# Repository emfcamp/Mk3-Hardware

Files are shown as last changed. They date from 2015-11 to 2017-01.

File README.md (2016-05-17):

Hardware
========

Hardware for the TiLDA MKπ Badge for [Electromagnetic Field
2016](https://www.emfcamp.org).

Key Specs
---------
* [STM32L486VGT6](http://www.st.com/content/st_com/en/products/microcontrollers/stm32-32-bit-arm-cortex-mcus/stm32l4-series/stm32l4x6/stm32l486vg.html):
  80MHz ultra-low-power ARM Cortex M4 microcontroller. 1MB Flash, 128KB
  SRAM, USB2. Micropython compatible.
* [CC3100MOD](http://www.ti.com/product/CC3100MOD) SimpleLink WiFi
  Network Processor.
* [LSM6DS3](http://www.st.com/content/st_com/en/products/mems-and-sensors/inemo-inertial-modules/lsm6ds3.html)
  3D accelerometer/gyro.
* [LIS3MDL](http://www.st.com/content/st_com/en/products/mems-and-sensors/e-compasses/lis3mdl.html)
  3D magnetometer.

License
-------
Copyright Electromagnetic Field Ltd. 2016

This documentation describes Open Hardware and is licensed under the
CERN OHL v. 1.2.  You may redistribute and modify this documentation
under the terms of the CERN OHL v.1.2. (http://ohwr.org/cernohl or the
LICENSE file in this repository). This documentation is distributed
WITHOUT ANY EXPRESS OR IMPLIED WARRANTY, INCLUDING OF MERCHANTABILITY,
SATISFACTORY QUALITY AND FITNESS FOR A PARTICULAR PURPOSE. Please see
the CERN OHL v.1.2 for applicable conditions.

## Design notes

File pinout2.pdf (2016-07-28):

PA0 | PA1 | PA2 | PB11
X1 | X2 | X3 | X4

WS2812

X1 | X2 | X3 | X4

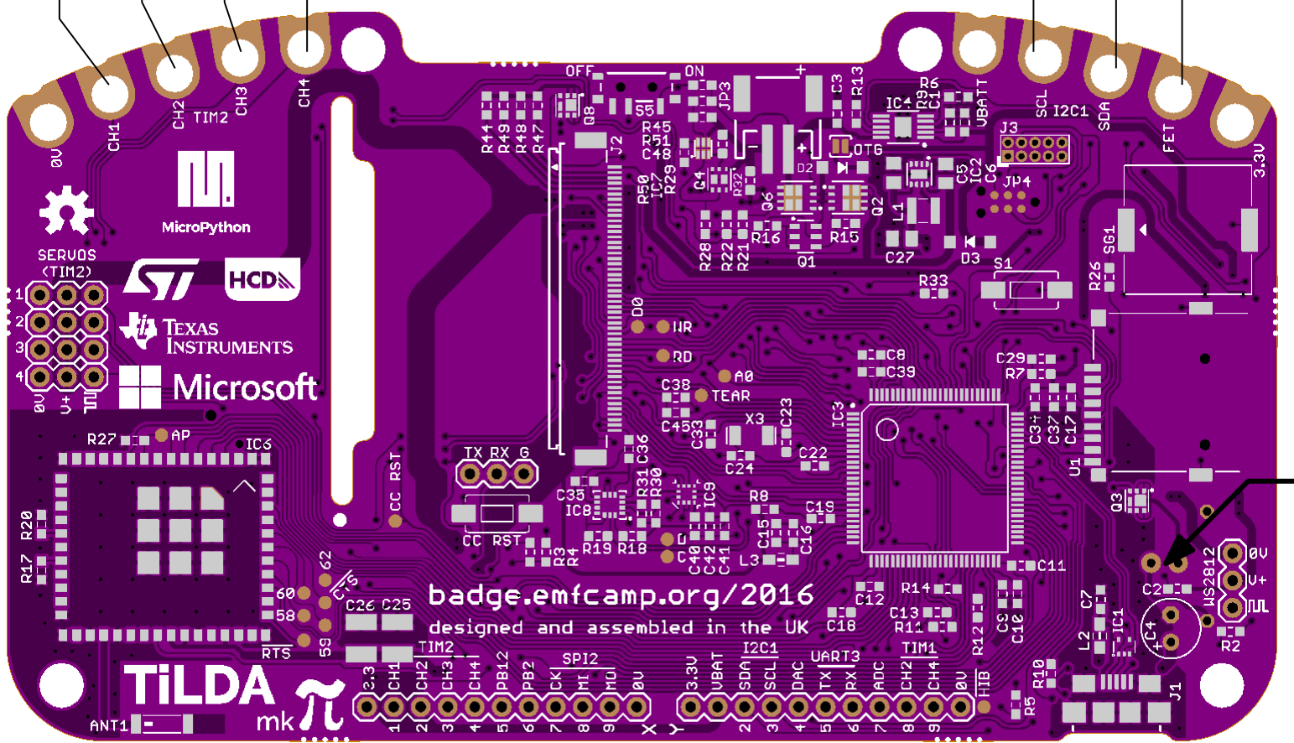
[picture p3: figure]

X1
X2
X3
X4

UART4
TX | RX
| TIM5
CH1 | CH2 | CH3

TIM2
CH1 | CH2 | CH3 | CH4
| ADC

## name

## Pin name

## Key peripherals

## Micropython

Y3 | Y2
PB9 | PB8
Y2 | Y3
PC7

## LED TORCH

I2C1
SDA | SCL

TIM4
CH4 | CH3

TIM4
CH2

## LED TORCH

This pin is open
drain | through | a
N-channel | FET.
Can | be | used
to | drive | higher
current loads

WS2812

## LED TORCH

PB13

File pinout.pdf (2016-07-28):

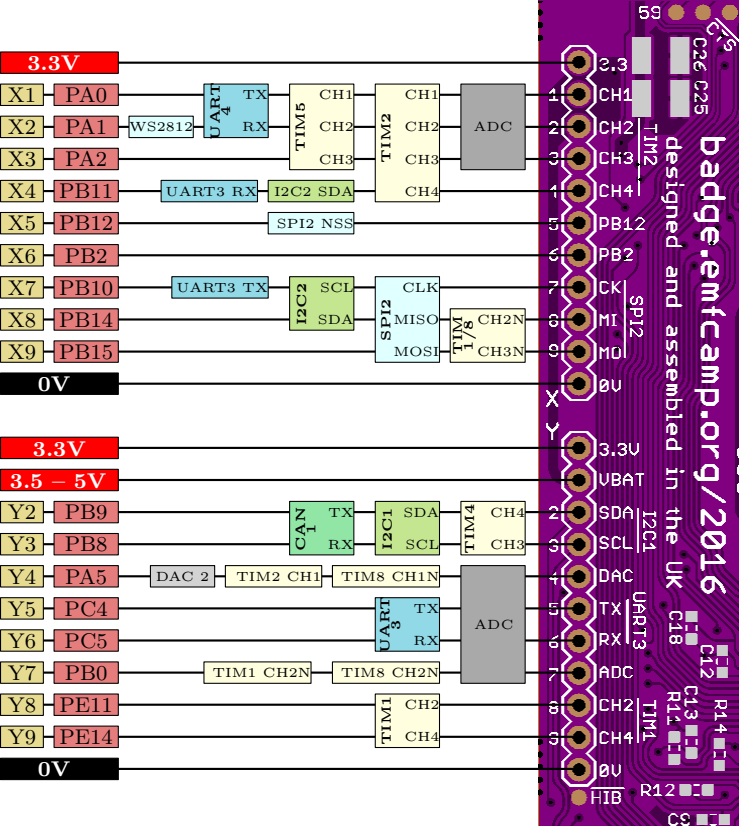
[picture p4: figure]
TIM2; CLK; MISO; MOSI; SPI2; SPI2 NSS; SDA; SCL; UART; TIM5; I2C2 SDA; UART3 TX; CAN; DAC 2; TIM2 CH1; TIM8 CH1N; TIM1 CH2N; TIM8 CH2N; TIM4; TIM1; TIM 1/8; UART3 RX; ADC

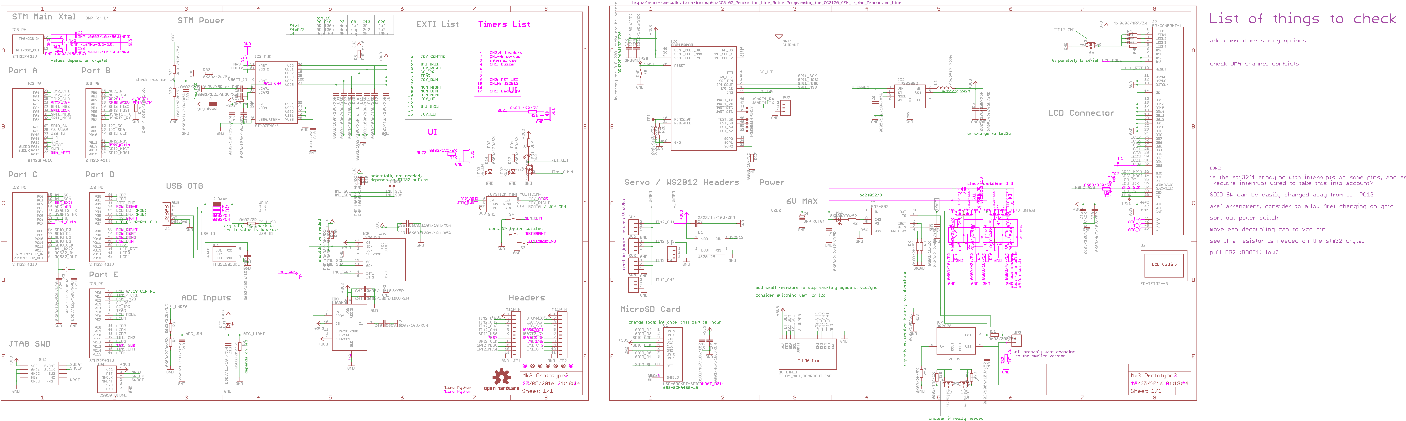
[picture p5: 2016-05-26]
diff v2_3.png

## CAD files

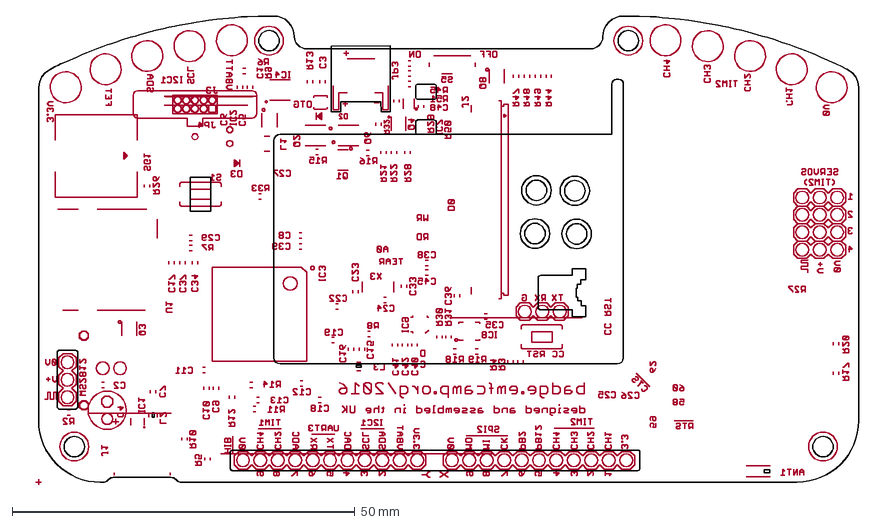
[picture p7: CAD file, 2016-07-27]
case-final.dxf
122.9 x 68.4 mm

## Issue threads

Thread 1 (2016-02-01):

Board Prototype 1 Issues

mattbrejza, 2016-02-01:
Potential leakage through R45 if battery cutoff is active but power switch is on. Leakage of 220K us ~16uA, so either increase this resistor, or rework the power section a bit

dpslwk, 2016-08-15:
No longer an issue

Closed 2016-08-15.

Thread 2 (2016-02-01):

Prototype -> Production Changes

mattbrejza, 2016-02-01:
Consider replacing 0R with solder jumpers

dpslwk, 2016-08-15:
No longer an issue

Closed 2016-08-15.

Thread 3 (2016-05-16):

Prototype 2 Issues

mattbrejza, 2016-05-16:
Check if WS2812 is fine on 3.3V, otherwise move to Vbat

mattbrejza, 2016-05-18:
consider switching PA5 and PE11 for DAC on external headers

mattbrejza, 2016-05-18:
consider connecting WS2812 to a timer pin

dpslwk, 2016-05-19:
Missing drill hole for screen mounting/location peg

‘RepRap’ Matt

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

dpslwk, 2016-05-19:
Move the CC serial header so its not under the screen

‘RepRap’ Matt

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

dpslwk, 2016-05-19:
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

Cutout example for screen ribbon

mattbrejza, 2016-05-19:
round corners near 3.3V/0V holes more

mattbrejza, 2016-05-19:
remove HSE and wire touchscreen

mattbrejza, 2016-05-19:
switch A/B and joystick

Jonty, 2016-05-19:
find wurth electronik passives we can swap in

mattbrejza, 2016-05-19:
move 5mm LED more inwards

mattbrejza, 2016-05-19:
look at buzzer options

dpslwk, 2016-05-19:
thinking we should move the LED to the bottom of the board/below the SD socket, so its not in you hand when you hold the badge

mattbrejza, 2016-05-19:
fiducials in opposite corners

dpslwk, 2016-05-19:
do something with the 11 way connectors so they are in something we can buy and does not need modifying
pin header socket size are normally  2,3,4,5,6,8,10.15,16,20,25

mattbrejza, 2016-05-20:
change footprints of microusb, switches to final ones

mattbrejza, 2016-05-20:
consider only having tagconnect

dpslwk, 2016-05-20:
Keep the SWD JTAG, not everyone can afford a Tag connect as well as a debugger
We are not populating it but might buy ~100 headers and sell them

'RepRap' Matt

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

dpslwk, 2016-05-20:
6x6 Tac switch foot print could have smaller pads and a little closer together
also add fancy alps pads just in case

‘RepRap’ Matt

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

dpslwk, 2016-05-20:
See if we can get a Plastic lanyard clip sample asap and then check the  clip size and what hole it will need.

'RepRap' Matt

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

mattbrejza, 2016-05-21:
if connecting touchscreen, make sure goes to ADC2, leaving ADC1 for user

mattbrejza, 2016-05-22:
add testpoints to parallel control sigs + one data

mattbrejza, 2016-05-22:
increase resistor for charge LED

mattbrejza, 2016-05-22:
mark on the silk where to place the velcro for the battery

mattbrejza, 2016-05-23:
Comments moved to other issues

Closed 2016-05-23.

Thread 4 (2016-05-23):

Board 2 Issues - Outline, stop, footprints,  misc

mattbrejza, 2016-05-23:
|  Item | Notes  | Progress |
|---|---|---|
| Teardrops on final board, do some test runs on copy of brd file | | |
| Ant pad, less exposed copper and cream | | ✔|
| Round corners on lcd ribbon slot, use 2mm wire as template in milling layer | | ✔|
| Don't like combined SD footprint, needs work | Will fix once decided on final part |✔|
| round corners near 3.3V/0V holes more | MB - I think they're fine| ✔|
| round corners near USB/wifi more | |✔|
| Missing drill hole for screen mounting/location peg | what size drill? (see comment)|✔ |
| fiducials in opposite corners | | LWK check please ✔|
| Larger stop around mcu and fpc connector pads, or make sure board house removes fingers | | |
| change footprints of microusb, switches to final ones | | ✔ |
| Remove cream from tag connector |I think just a dpcbs stencil 'artifact' |✔ Confirmed, no action needed |
| find wurth electronik passives we can swap in | |✔ |
| 6x6 Tac switch foot print could have smaller pads and a little closer together also add fancy alps pads just in case | |✔ |
| See if we can get a Plastic lanyard clip sample asap and then check the  clip size and what hole it will need. | | |
| LWK to review LGA footprint pad/cream sizes |Make sure there not too small | |
| Finalize battery connector selection. Suggest looking at JST PA (locking pin, less wire stress | | PH fine ✔|
| rename net TIM1_CH1N to TIM8_CH2 (for LED FET) | | ✔|

mattbrejza, 2016-05-23:
Example image of screen peg: https://www.dropbox.com/s/eqn3t87pvbxqiao/IMG_4801.jpg?dl=0

dpslwk, 2016-08-15:
No longer an issue

Closed 2016-08-15.

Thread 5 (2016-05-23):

Board 2 Issues - Values

mattbrejza, 2016-05-23:
|  Item | Notes  | Progress |
|---|---|---|
| D2 and D3 need values in schematic |rate D3 to 2A | ✔|
| increase resistor for charge LED | | |
| look at brightness of all LEDs | | |
| decide on buzzer resistor | | |

dpslwk, 2016-08-15:
No longer an issue

Closed 2016-08-15.

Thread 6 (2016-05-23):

Board 2 Issues - Silk

mattbrejza, 2016-05-23:
|  Item | Notes  | Progress |
|---|---|---|
| Ic7 name and thicker silk | | ✔|
| Rotate c42-40 labels | |✔|
| R9 label rotate; R31 label rotate | |✔ |
| Ic7 label | | ✔|
| Increase screen slik outline line thickness to 0.15mm | | ✔|
| Remove place silk from 0603s | MB disagrees |✔ |
| Test pad names on silk | | ✔|
| Servo squiggle too small, 0.15-0.3 min thickness and clearance | | ✔|
| S5 J3 move names outside parts | |✔ |
| Duplicate conductive pad labels to both sides | |✔ |
| Q1 pin one mark bigger | |✔ |
| Make sure no silk labels are under screen ribbon (CC serial header is right now) | |✔ |
| Header pin function labels need moving away from numbers | |✔ |
| Remove silk on jtag header, add pin 1 mark | | ✔|
| mark on the silk where to place the velcro for the battery | | |
| Add XYZ indicator for IMU | | |
| Add label to stm32 rst |||

dpslwk, 2016-08-15:
No longer an issue

Closed 2016-08-15.

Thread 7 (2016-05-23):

Board 2 Issues - Placement and Routing

mattbrejza, 2016-05-23:
|  Item | Notes  | Progress |
|---|---|---|
| LGA12/LGA14 footprints mirrored  | Re-routing also needed  | ✔  |
| switch A/B and joystick | |✔ |
| Add option to bypass battery protection if not fitted | | ✔|
| remove HSE and wire touchscreen | touchscreen not yet confirmed. if connecting touchscreen, make sure goes to ADC2, leaving ADC1 for user | ✔|
| thinking we should move the LED to the bottom of the board/below the SD socket, so its not in you hand when you hold the badge; move 5mm LED more inwards | |✔|
| Move A, B LEDs away from screen | | ✔ |
| Add reset button for STM?| same switch as MENU? |✔ |
| X3 is long way from mcu, check ok| |✔ - its only 32kHz, and not that far |
| Can we get ic4 in something other than msop-10? |  | ✔ nope |
| Test pad  add more | add testpoints to parallel control sigs + one data ✔ | |
| Speaker too close to the edge | | ✔|
| Move the CC serial header so its not under the screen | | |
| consider switching PA5 and PE11 for DAC on external headers | |✔ |
| consider connecting WS2812 to a timer pin | |✔ |
| do something with the 11 way connectors so they are in something we can buy and does not need modifying pin header socket size are normally 2,3,4,5,6,8,10.15,16,20,25 | | |
| Check if WS2812 is fine on 3.3V, otherwise move to Vbat | | ✔|
| Check meander on usb trace | | ✔ close enough |
| Battery option 3 | |✔ |
| R23 sort out | |✔|
| Test point on CC_HIB | | ✔|

dpslwk, 2016-08-15:
No longer an issue

Closed 2016-08-15.

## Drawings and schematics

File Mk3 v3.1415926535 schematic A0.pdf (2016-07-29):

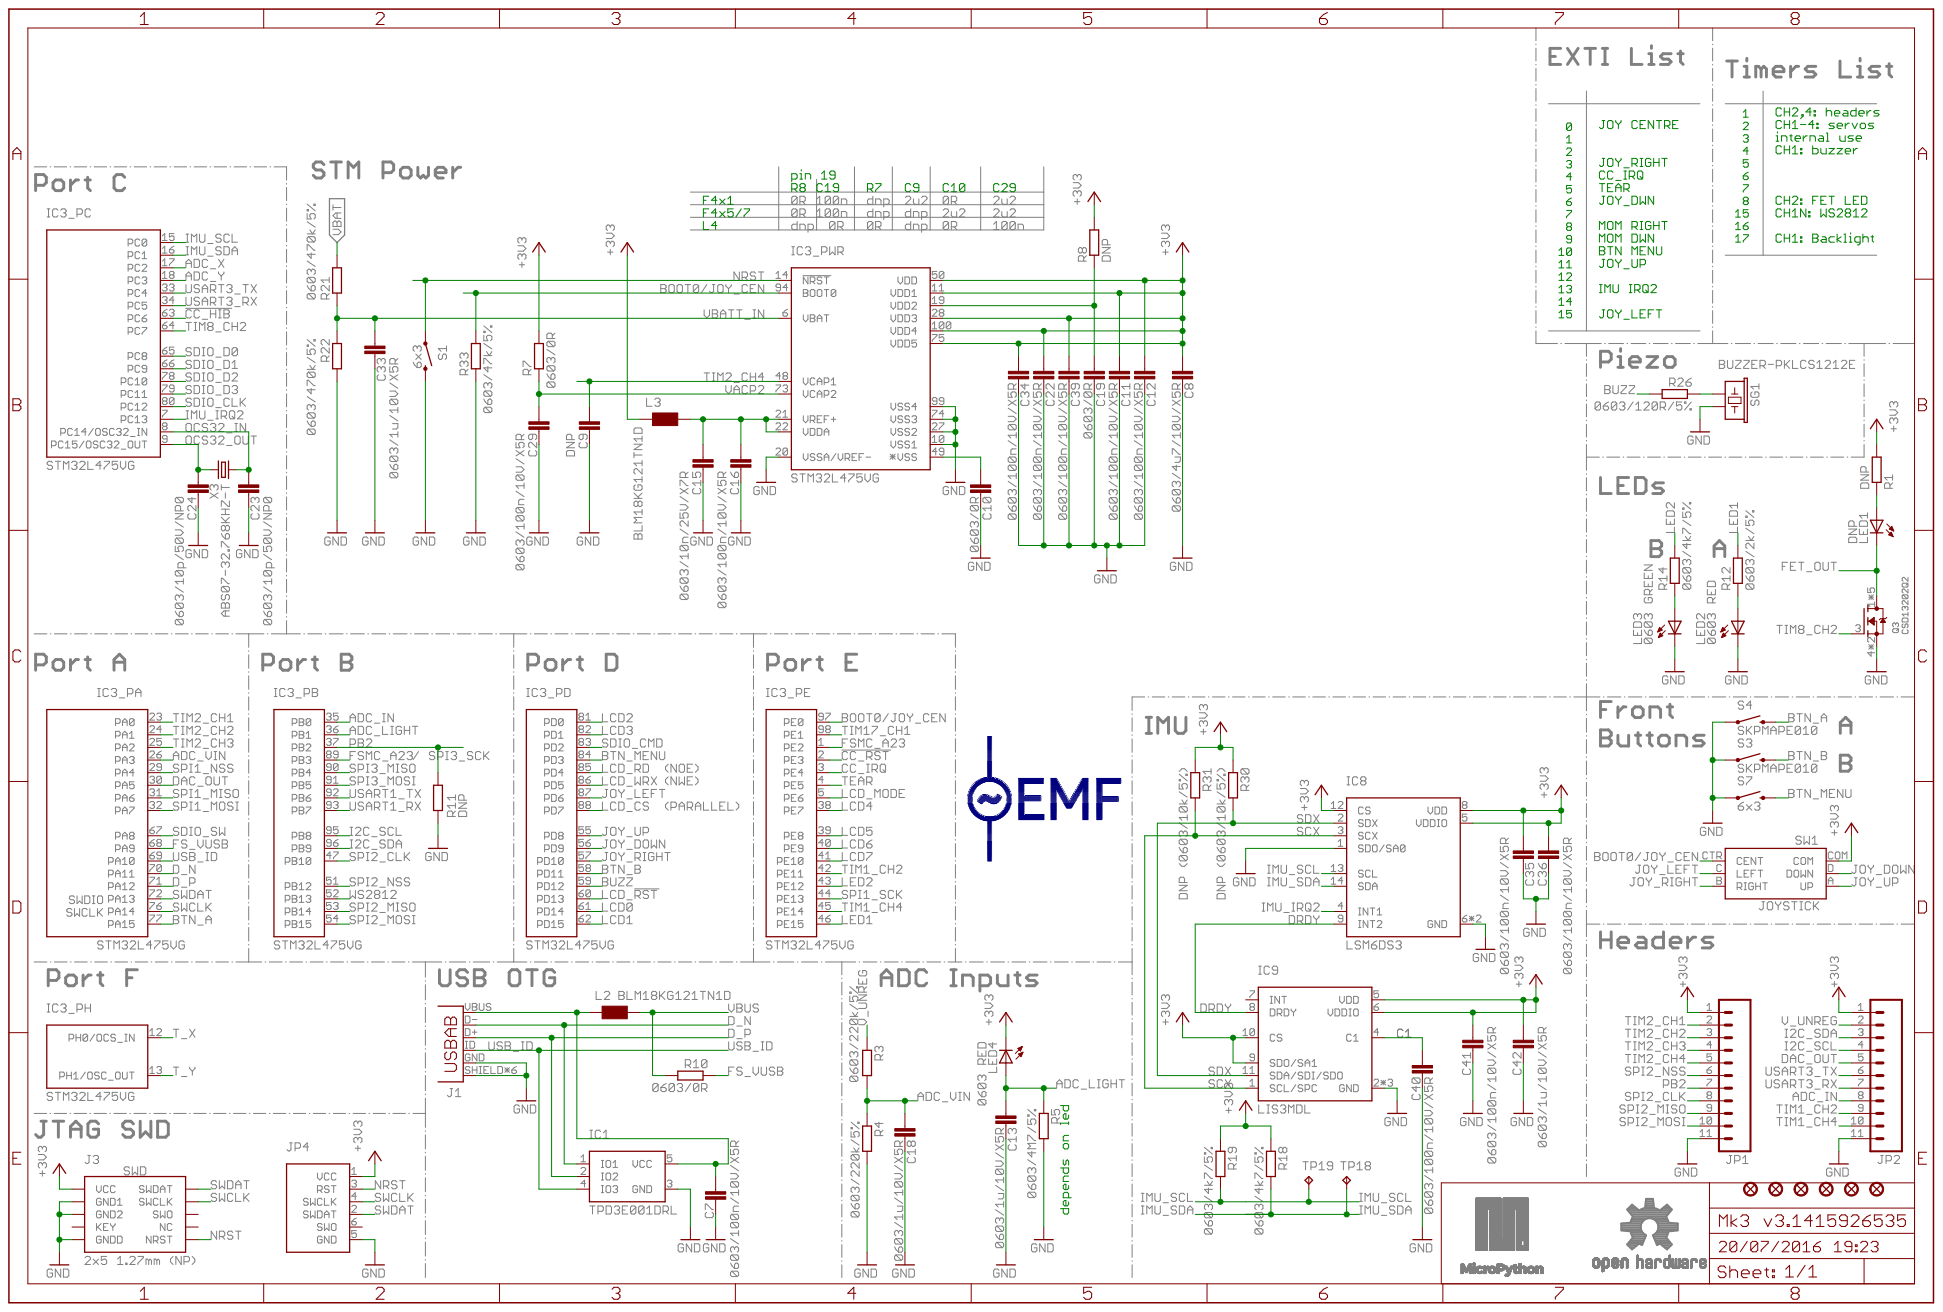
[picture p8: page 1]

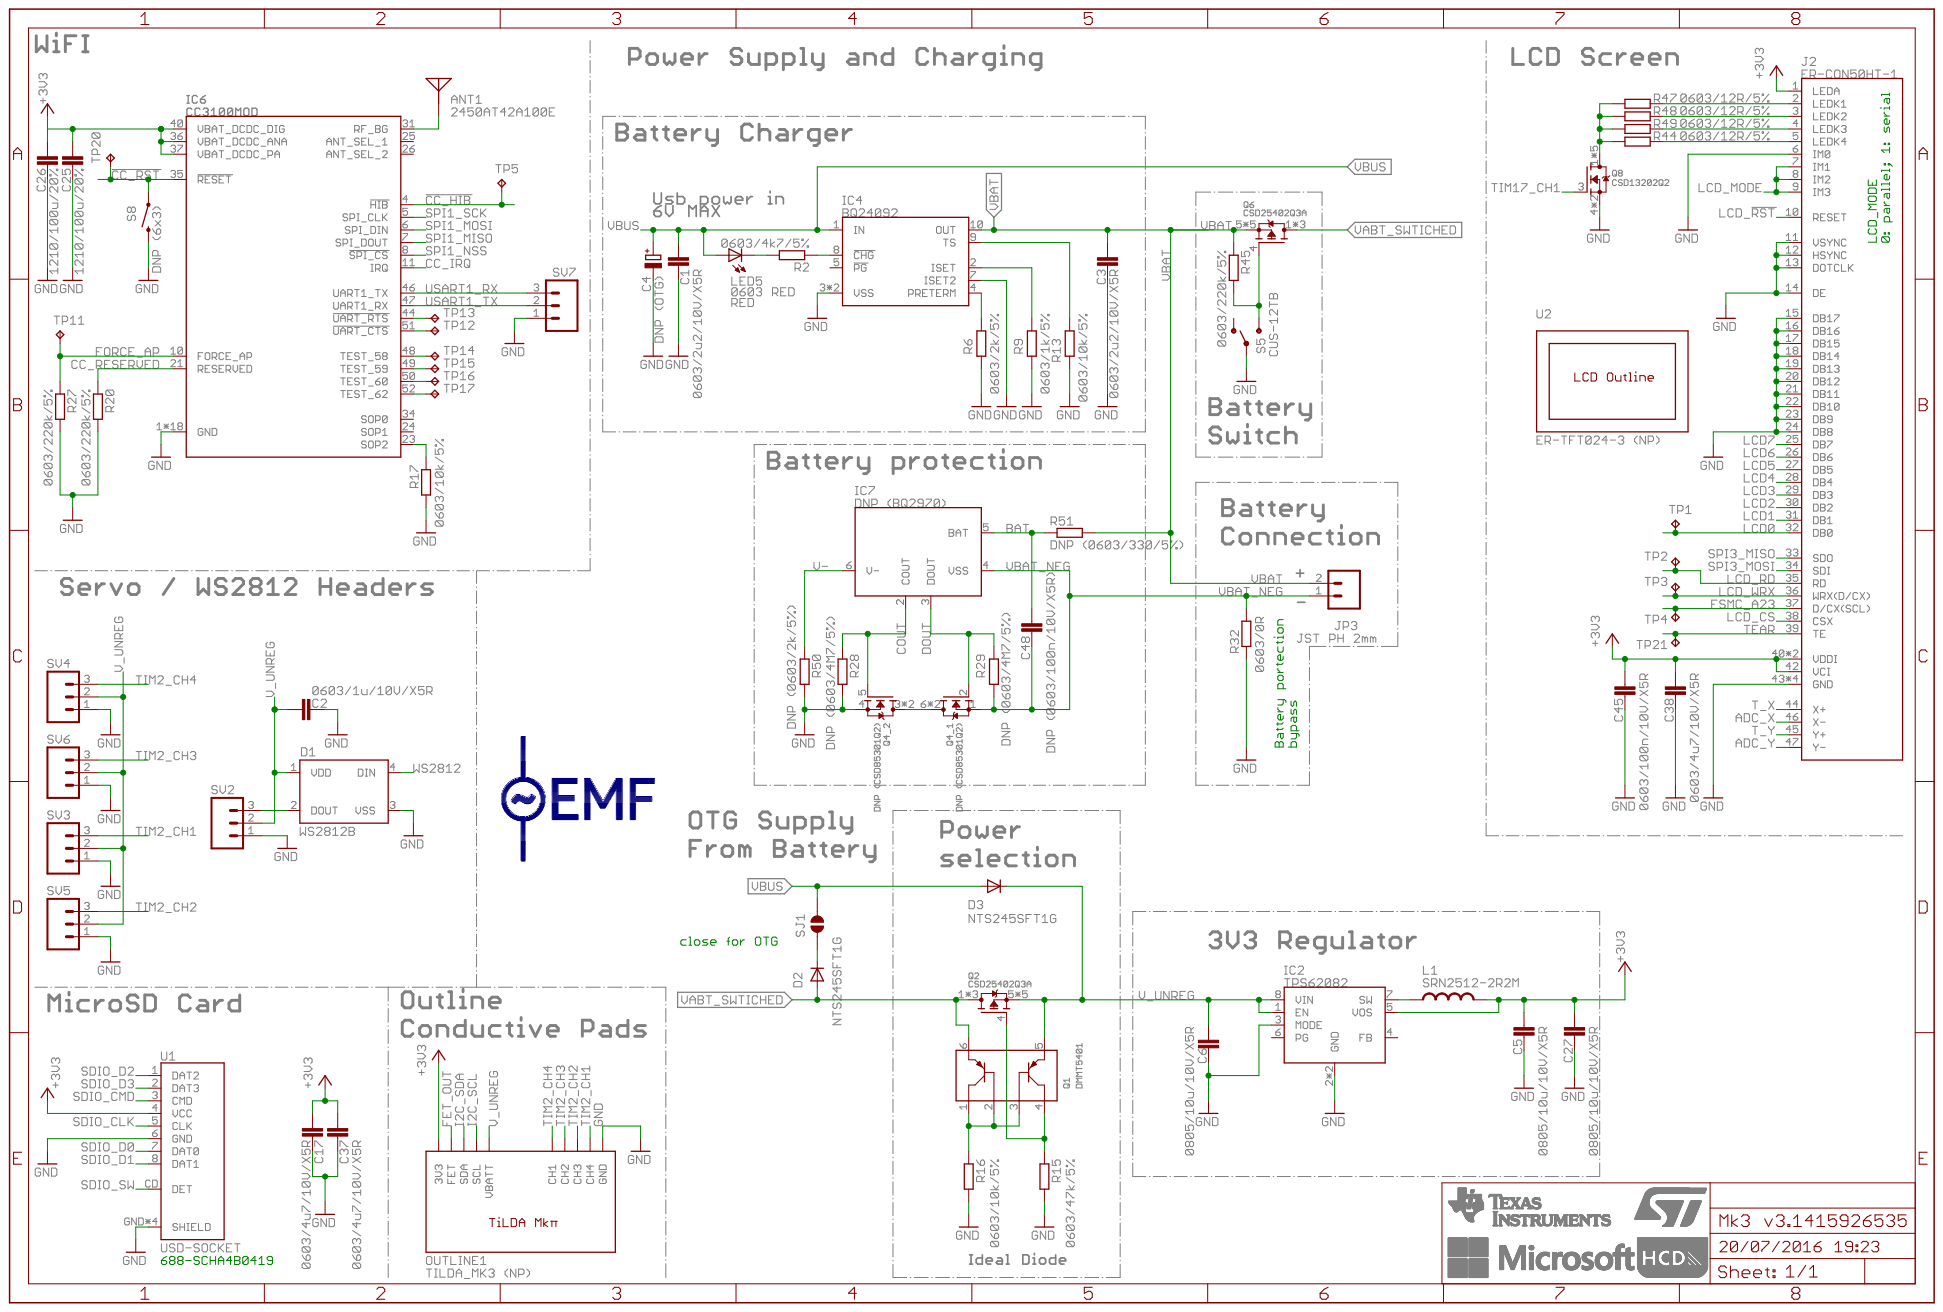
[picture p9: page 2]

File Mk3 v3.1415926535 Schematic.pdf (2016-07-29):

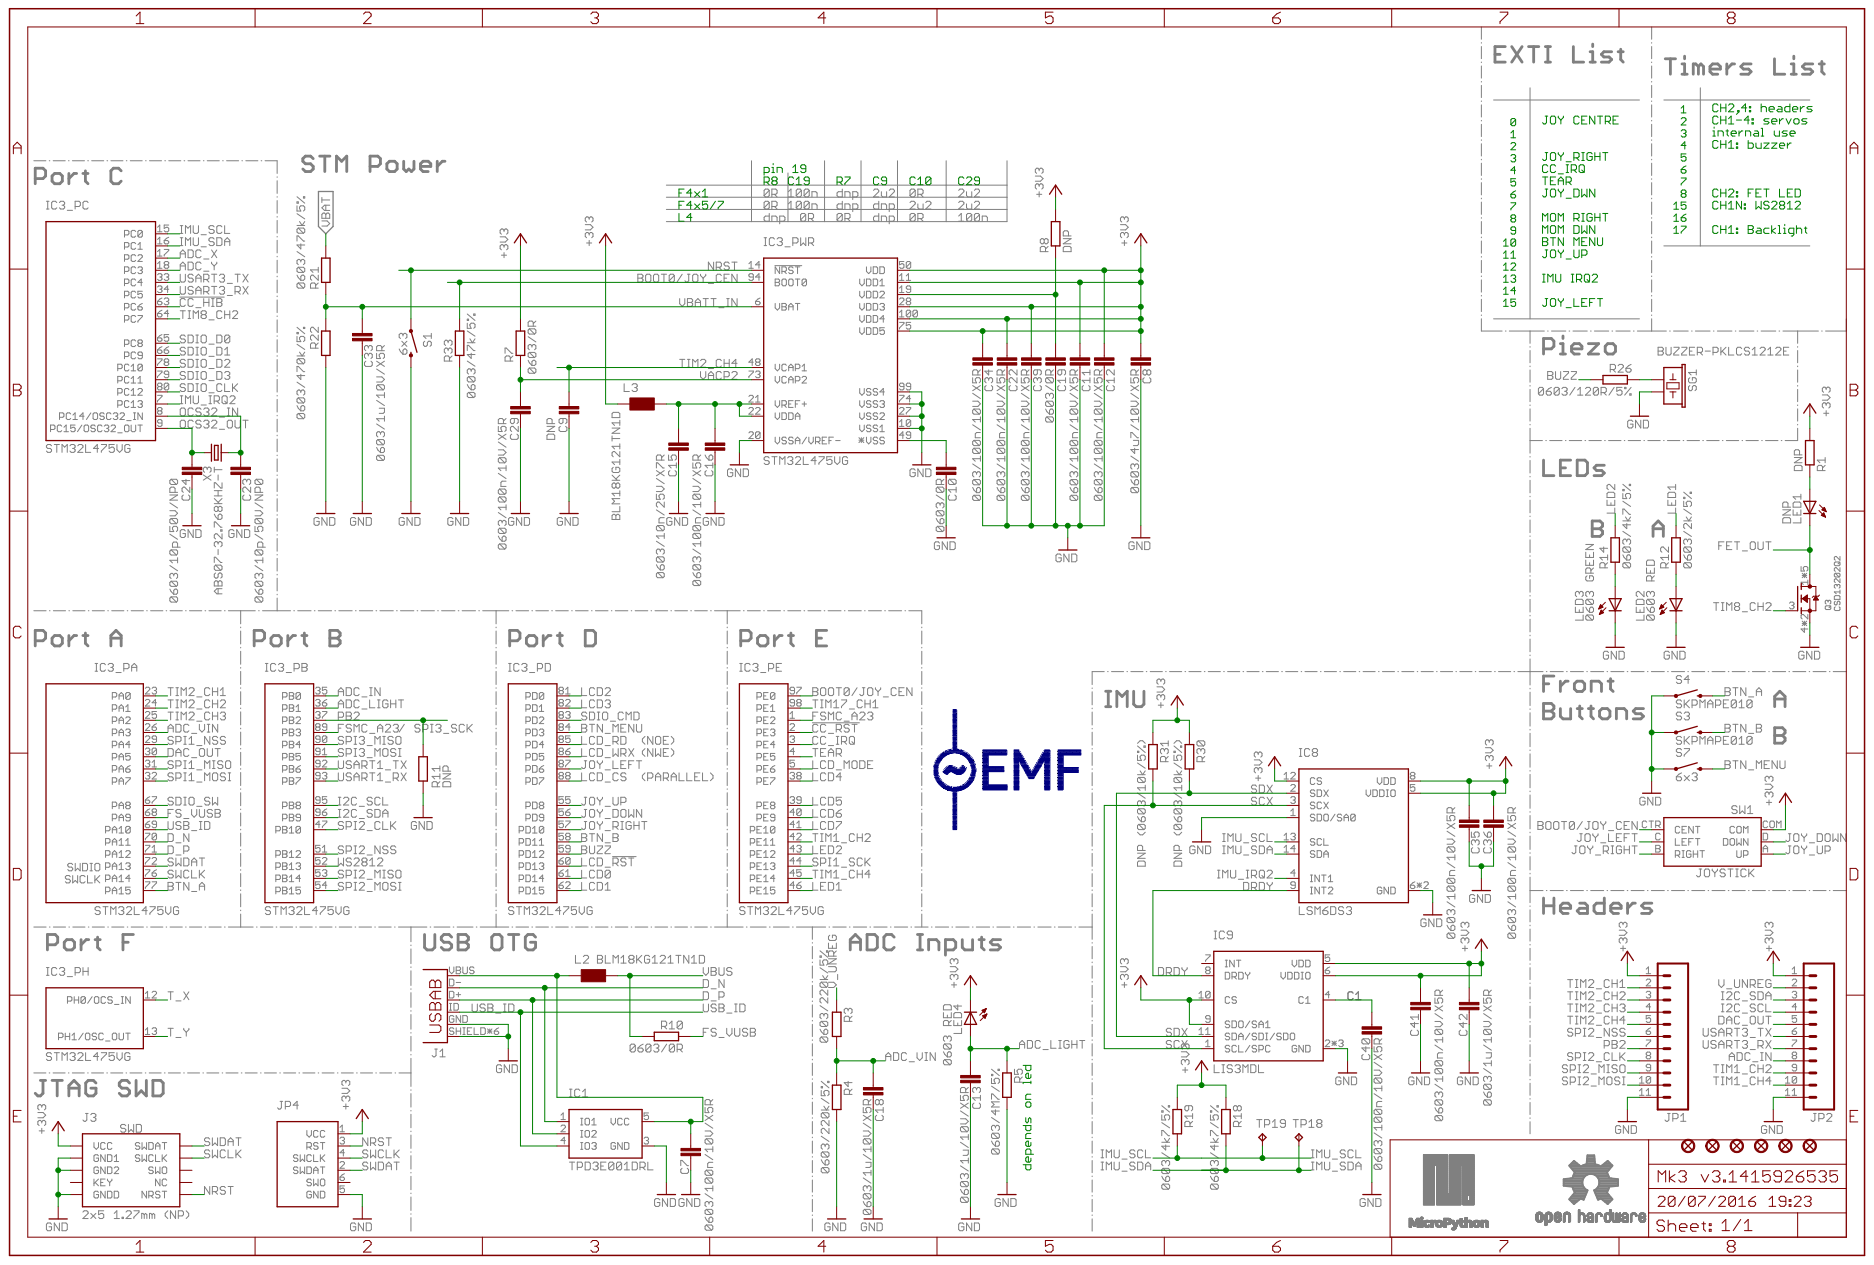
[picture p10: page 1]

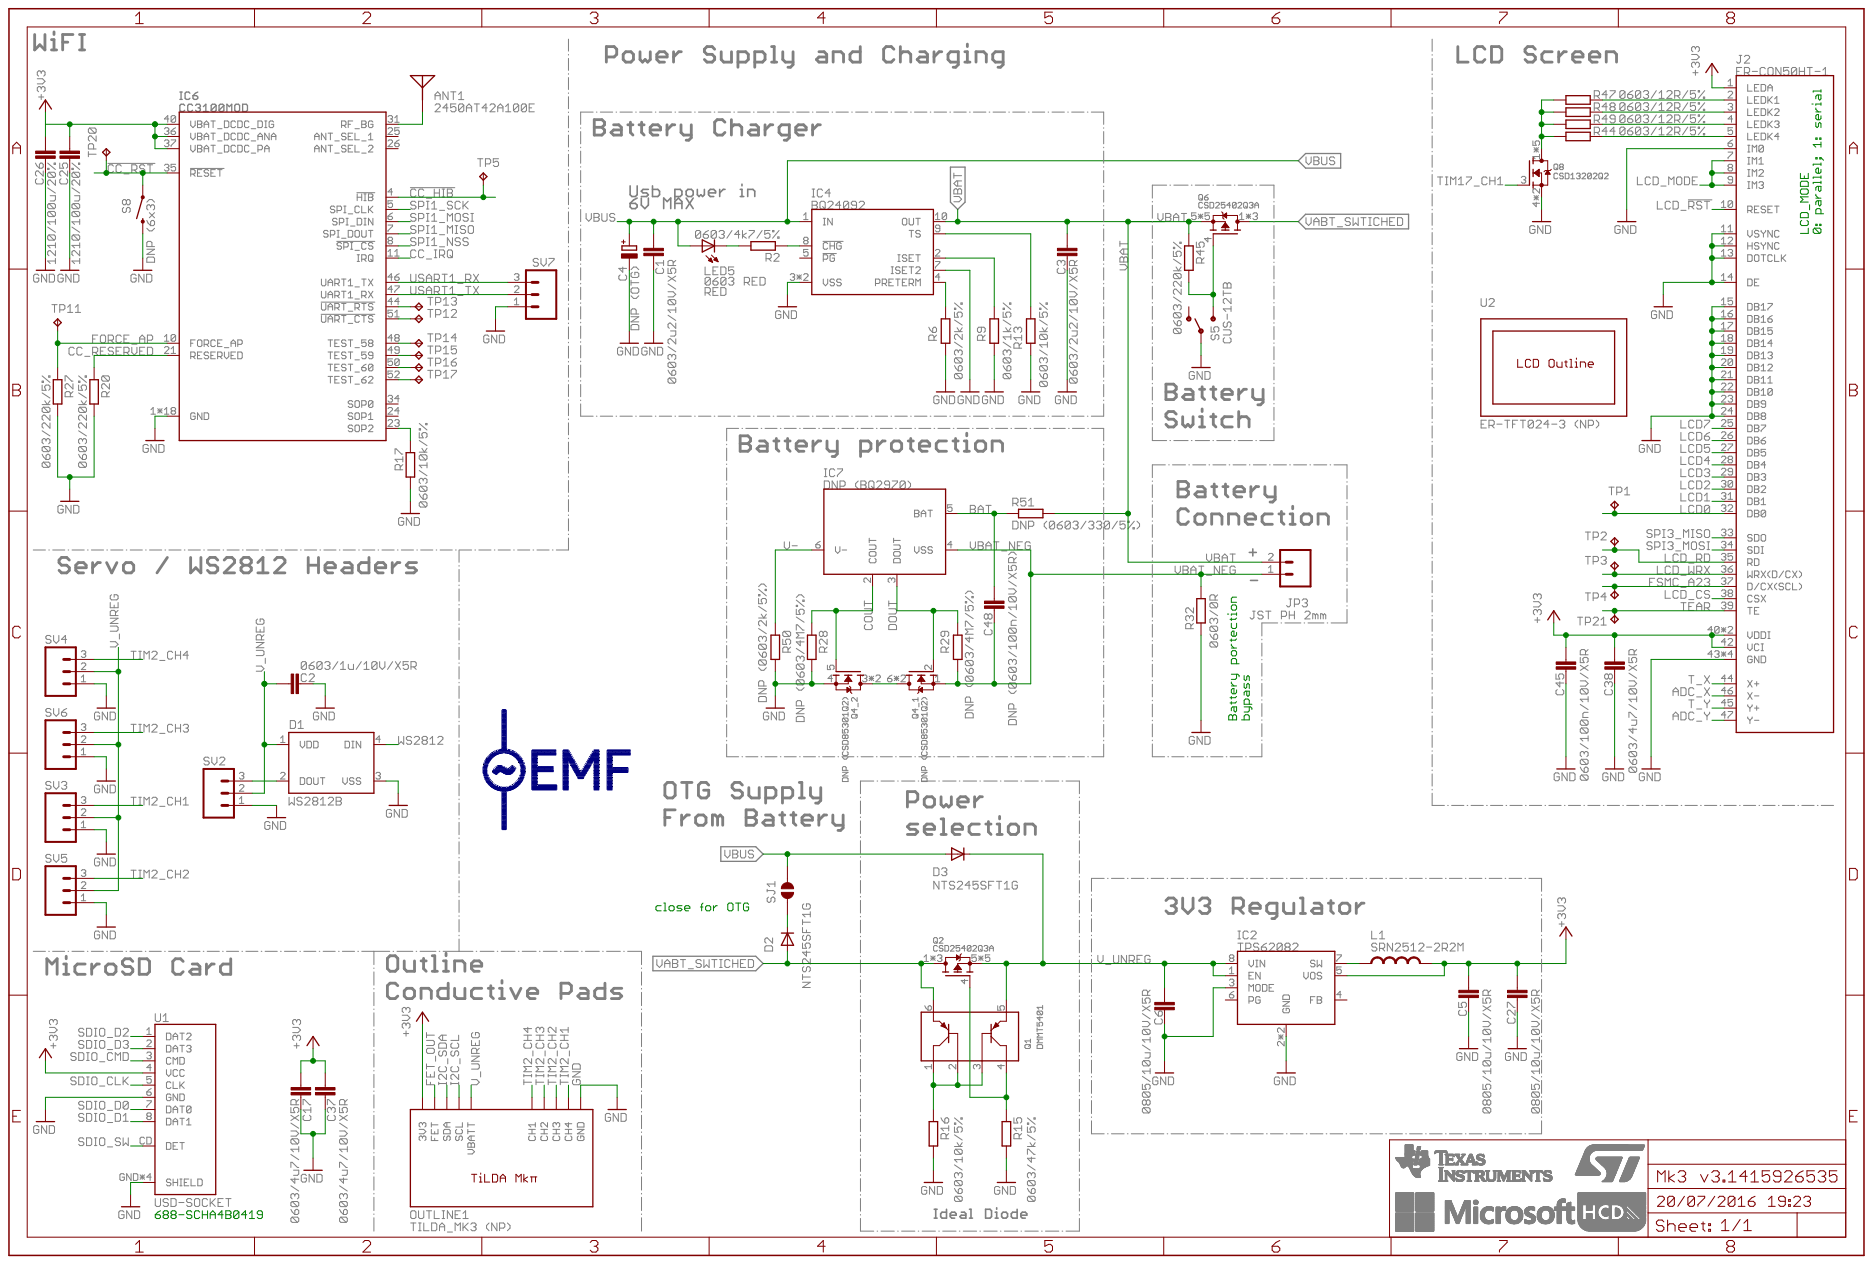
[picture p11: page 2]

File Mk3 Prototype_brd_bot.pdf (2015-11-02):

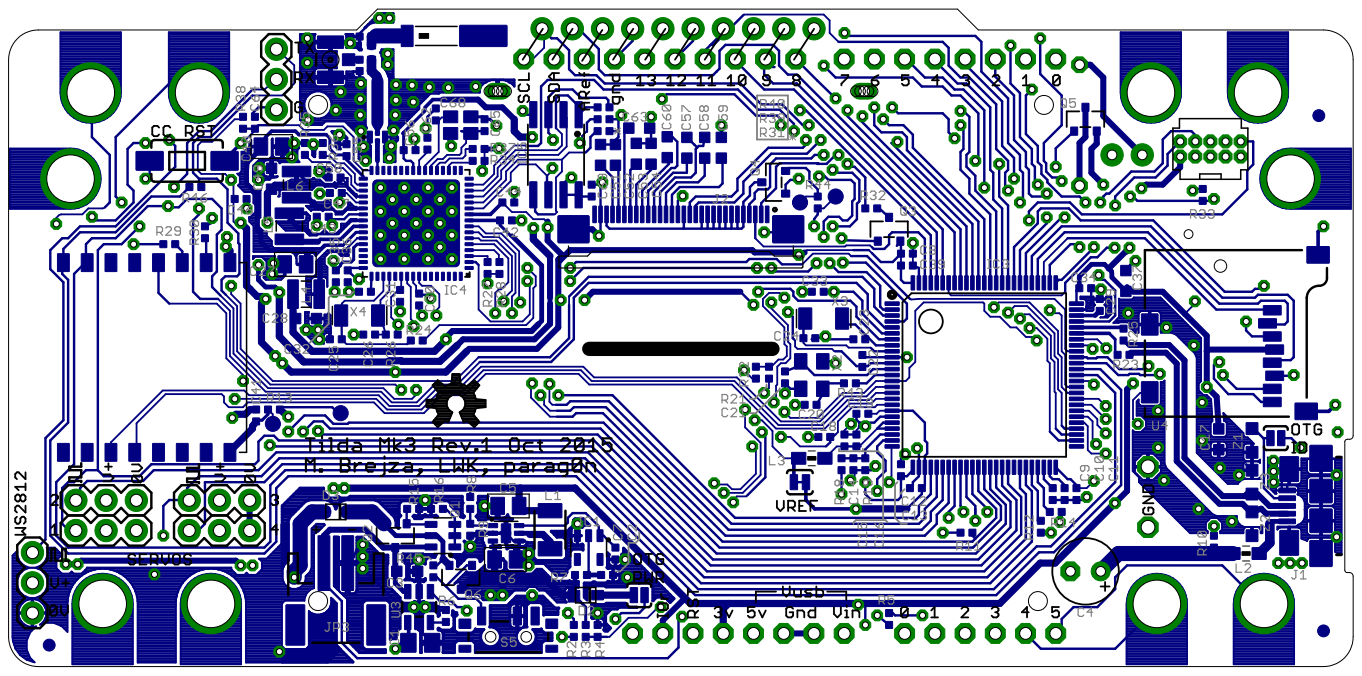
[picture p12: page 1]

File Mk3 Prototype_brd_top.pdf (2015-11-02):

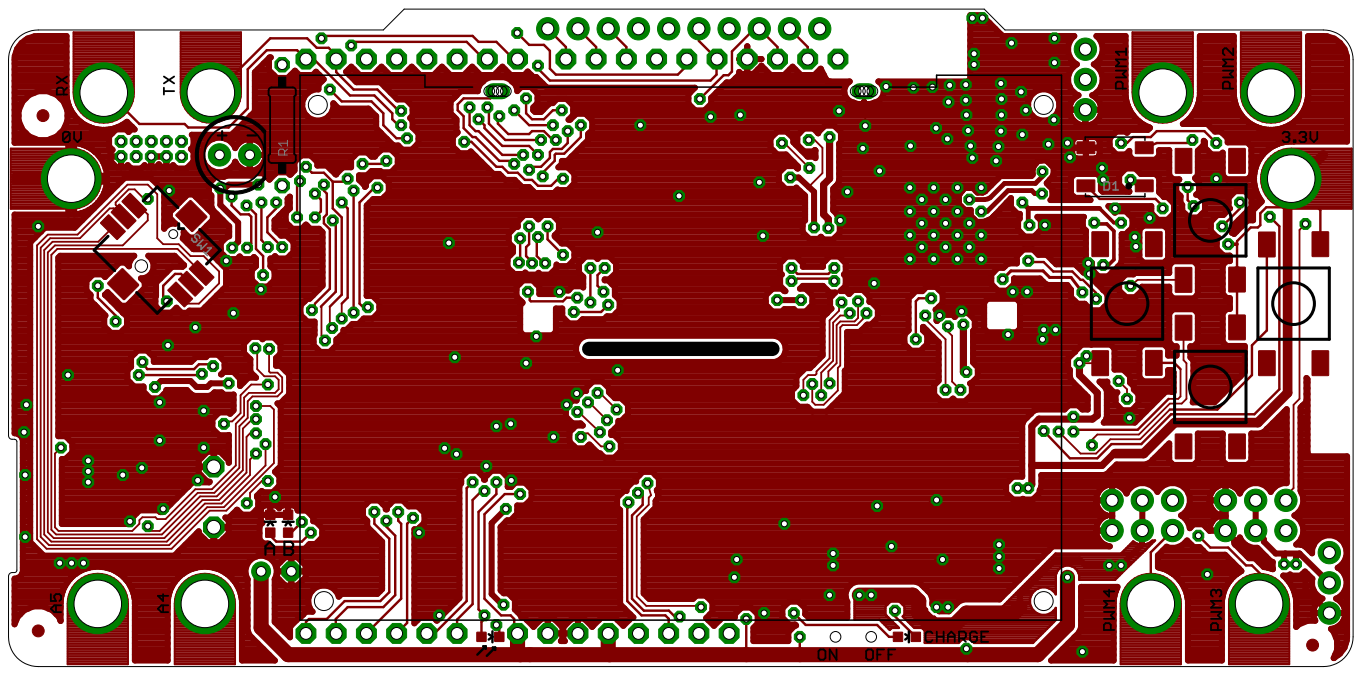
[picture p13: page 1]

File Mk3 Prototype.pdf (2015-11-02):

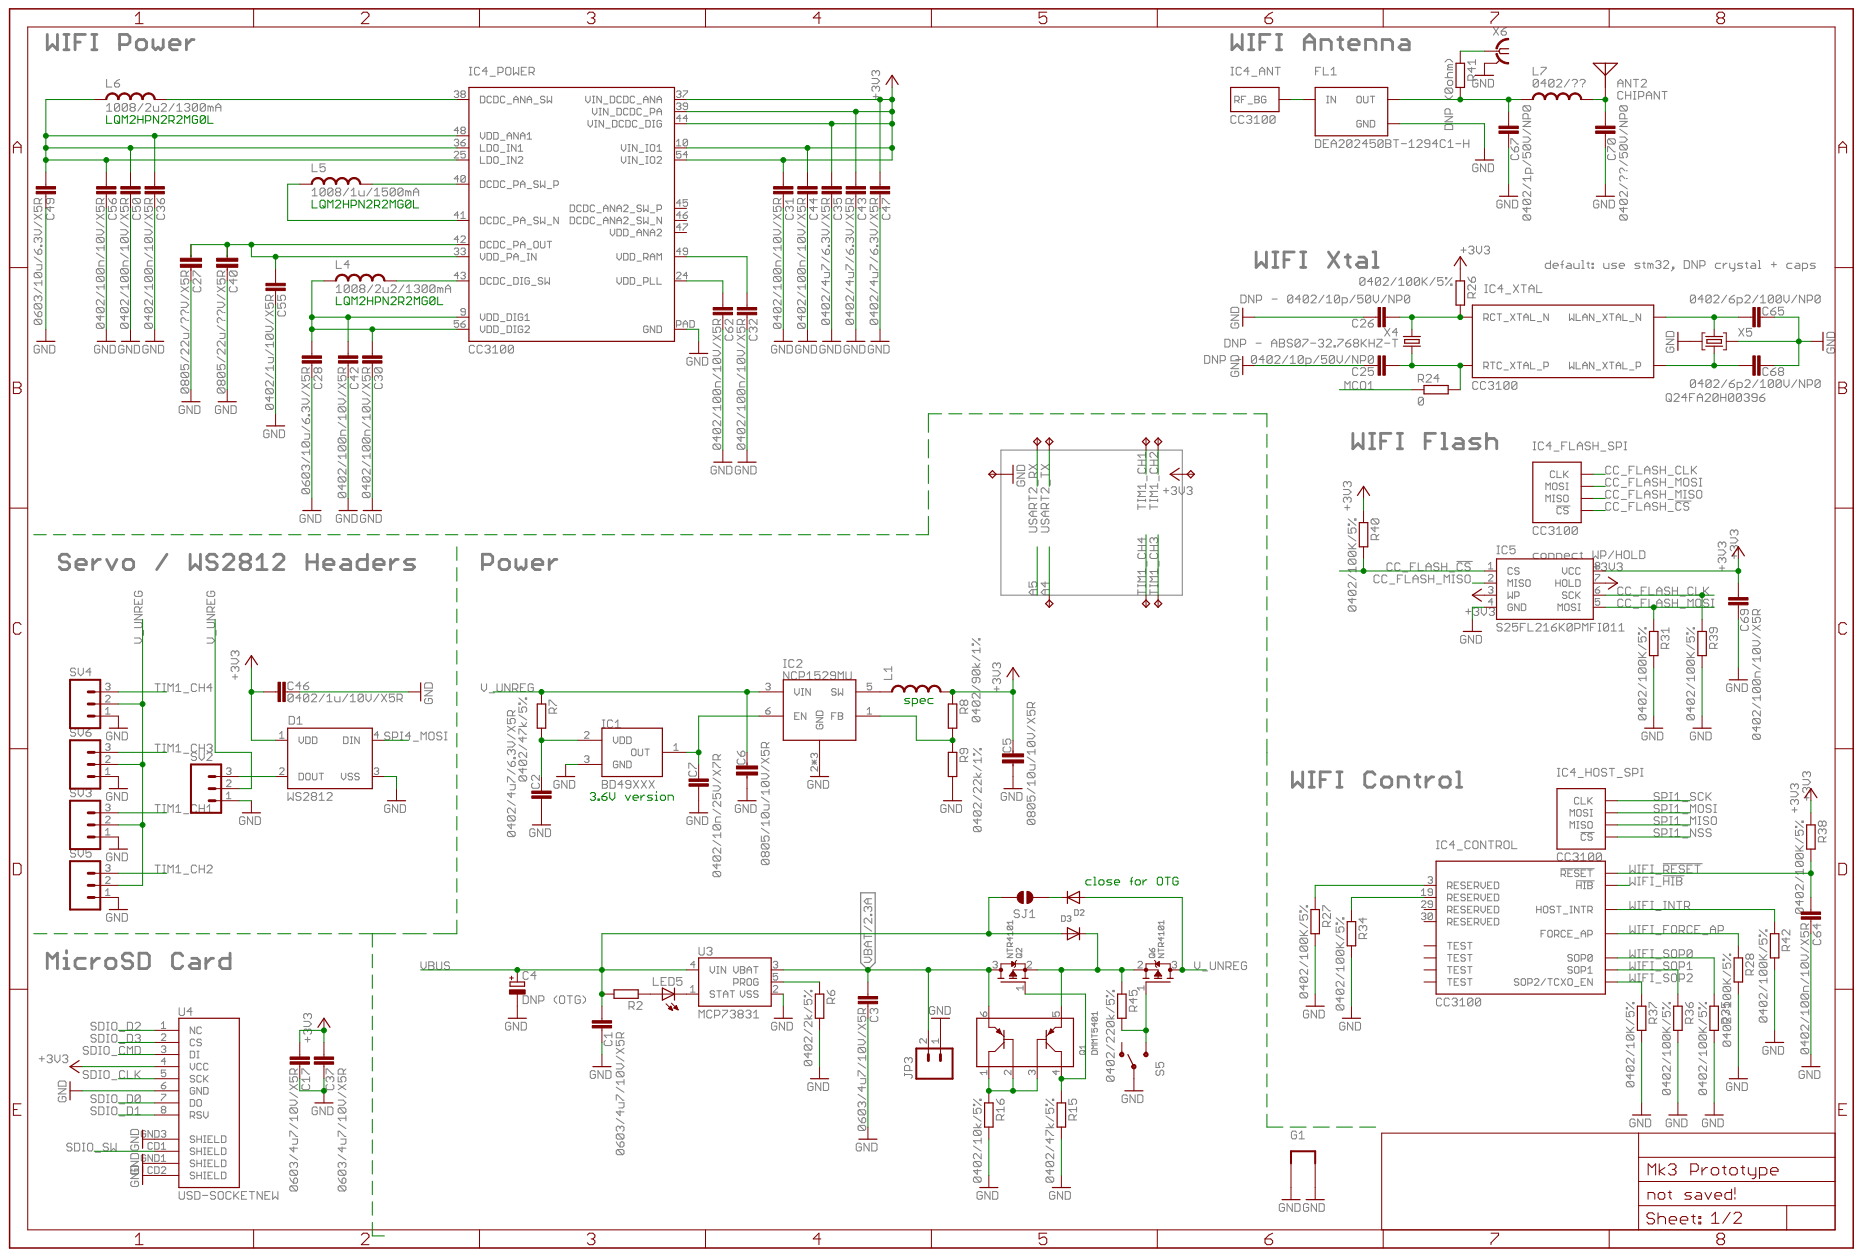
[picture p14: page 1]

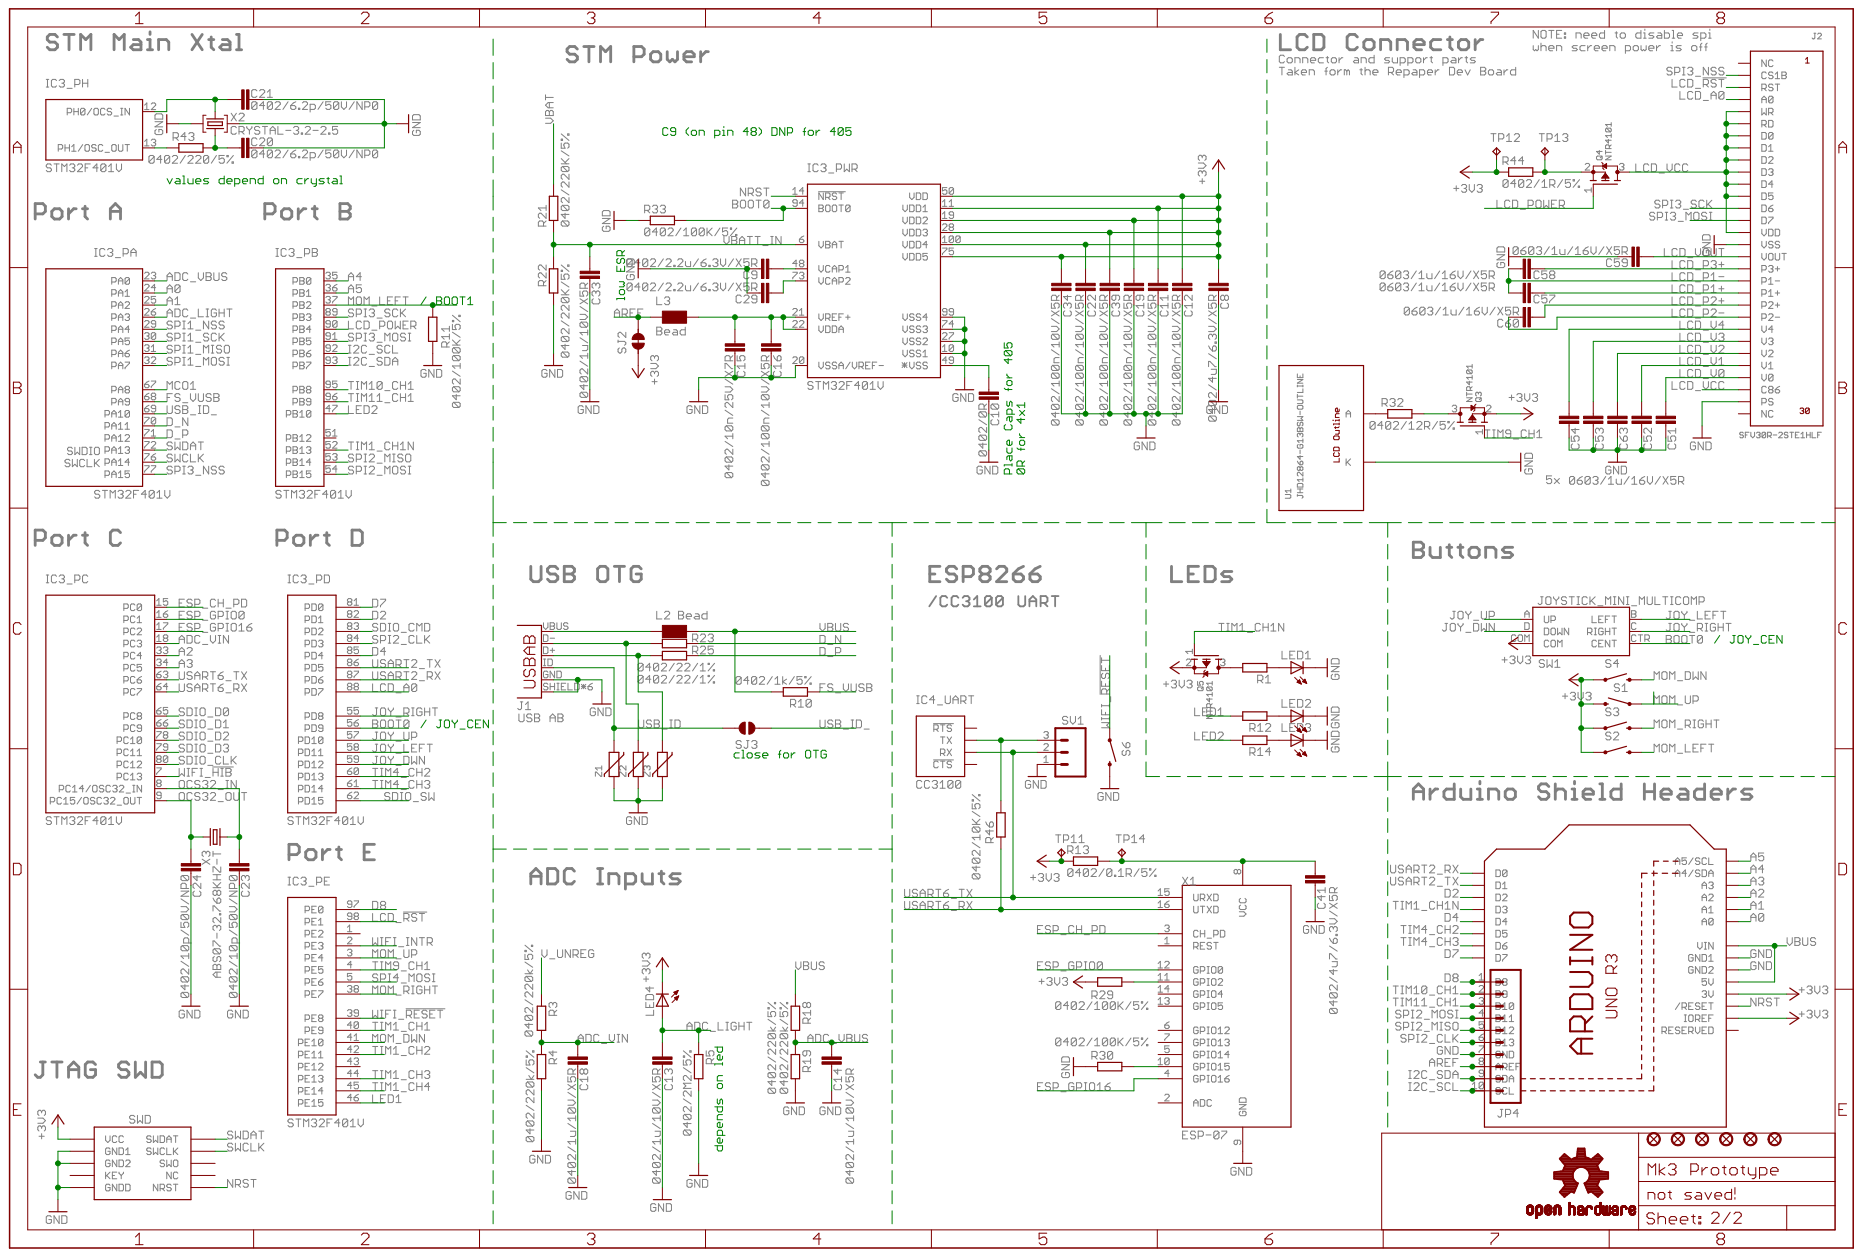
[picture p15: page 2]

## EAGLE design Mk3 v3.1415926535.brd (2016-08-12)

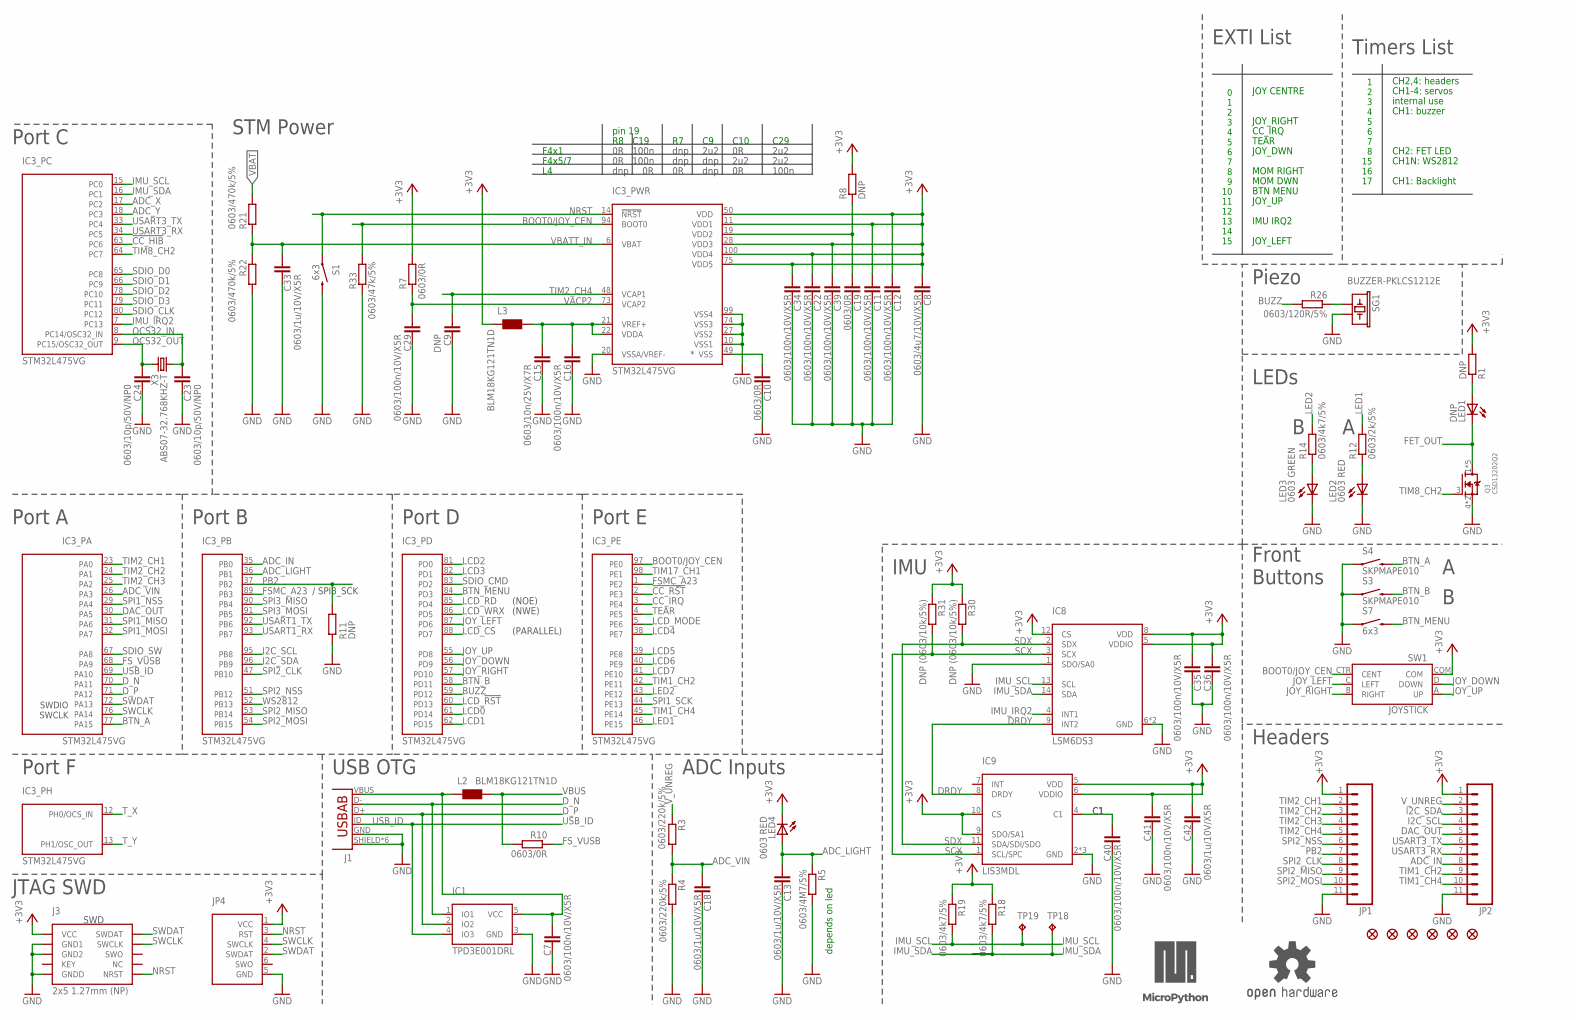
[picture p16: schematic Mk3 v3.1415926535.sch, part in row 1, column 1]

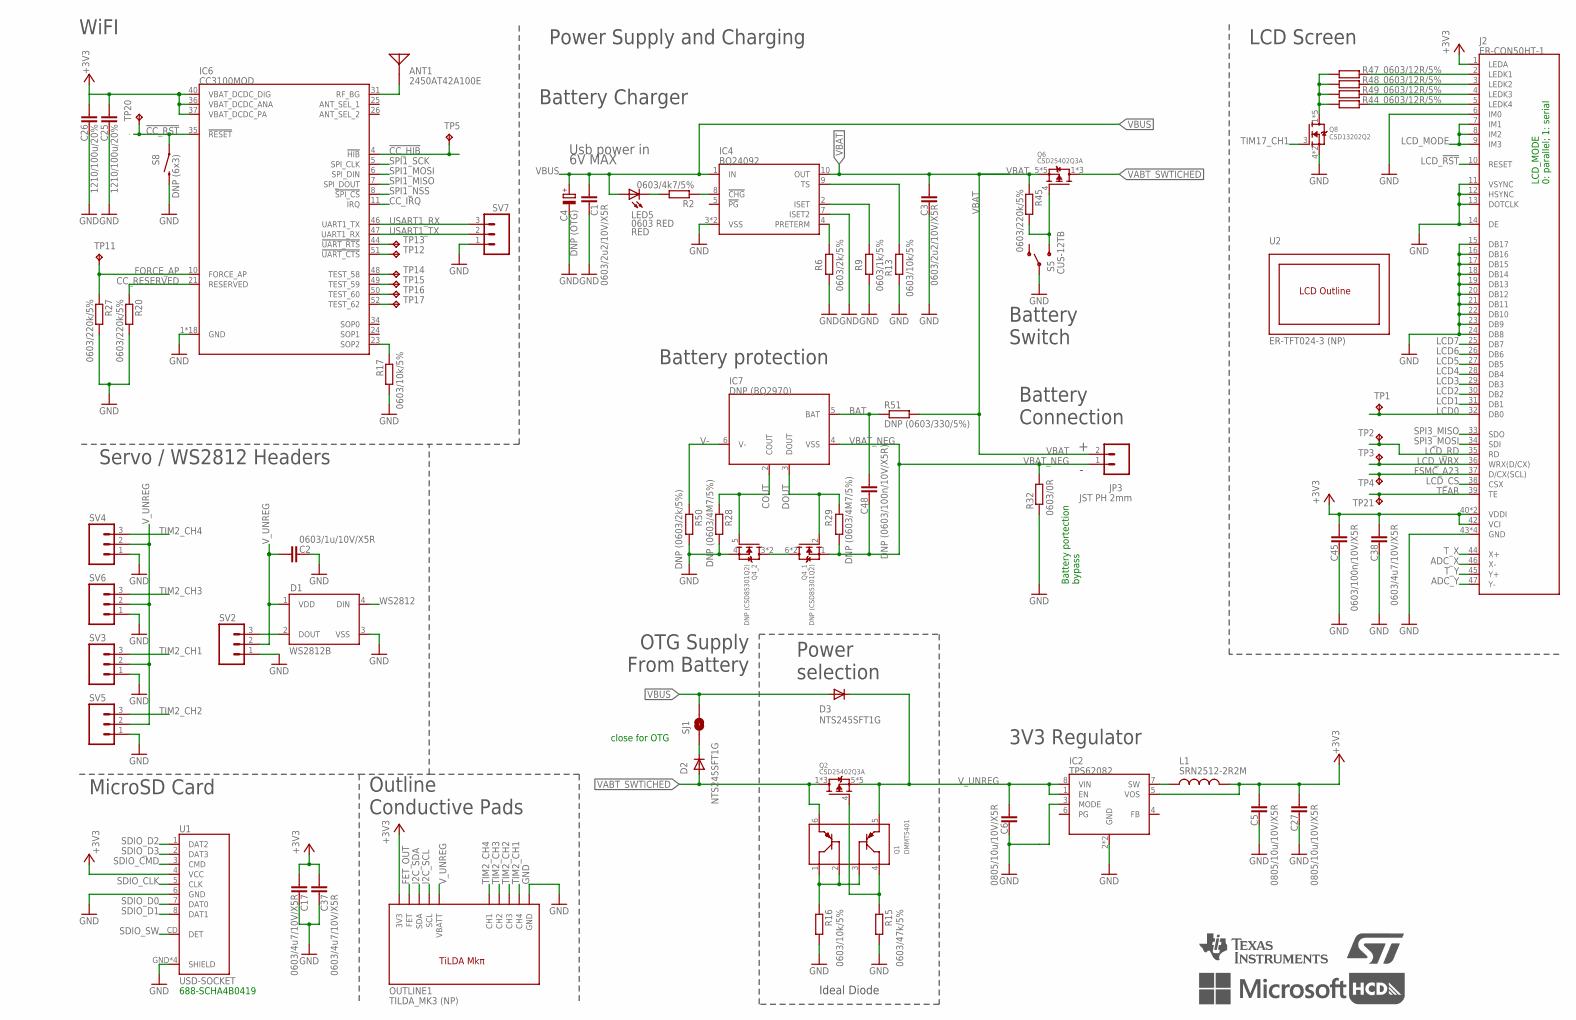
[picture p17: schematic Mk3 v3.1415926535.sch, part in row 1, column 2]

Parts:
ANT1: 2450AT42A100E; 2450AT42A100; FARNELL 2148522
C1, C3: 0603/2u2/10V/X5R; C0603K-SMALL
C2, C13, C18, C33, C42: 0603/1u/10V/X5R; C0603K-SMALL
C4: DNP (OTG); E2,5-6
C5, C6, C27: 0805/10u/10V/X5R; C0805-N
C7, C11, C12, C16, C22, C29, C34, C35, C36, C39, C40, C41, C45: 0603/100n/10V/X5R; C0603K-SMALL
C8, C17, C37, C38: 0603/4u7/10V/X5R; C0603K-SMALL
C9: DNP; C0603K-SMALL
C10, C19: 0603/0R; C0603K-SMALL
C15: 0603/10n/25V/X7R; C0603K-SMALL
C23, C24: 0603/10p/50V/NP0; C0603K-SMALL
C25, C26: 1210/100u/20%; C1210K; FARNELL 1828817
C48: DNP (0603/100n/10V/X5R); C0603K-SMALL
D1: WS2812B
D2, D3: NTS245SFT1G; SOD123
FID1, FID2, FID3, FID4, FID5, FID6: FIDUCIAL1X2.5-STOP; FIDUCIAL-1X2.5-STOP
IC1: TPD3E001DRL; DRL-5; FARNELL 1603422
IC2: TPS62082; WSON8; FARNELL 2064227
IC3: STM32L475VG; TQFP100; FARNELL 2432116
IC4: BQ24092; HVSSOP10; FARNELL 2323723
IC6: CC3100MOD; CC3100MOD-LWK; MOUSER 595-3100MODR11MAMOBR
IC7: DNP (BQ2970); WSON-6; FARNELL 2425793
IC8: LSM6DS3; LGA14; FARNELL 2474253
IC9: LIS3MDL; LGA12; FARNELL 2433083
J1: ZX62-AB-5PA(11); USB-AB-MICRO-SMD_LWK; FARNELL 2293755
J2: ER-CON50HT-1; FH12-50S-0.5SH
J3: 2x5 1.27mm (NP); PINHEAD_2X05_127; FARNELL 1865285
JP1, JP2: (NP); 1X11
JP3: JST PH 2mm; JST-2-SMD; FARNELL 9492615
JP4: (NP); TC2030-MCP-NL
L1: SRN2512-2R2M; 1008; FARNELL 2428203
L2, L3: BLM18KG121TN1D; WUERTH-0805; FARNELL 1781089
LED1: DNP; LED5MM
LED2, LED4, LED5: 0603 RED; LED-0603-CORRECT; FARNELL 2449874
LED3: 0603 GREEN; LED-0603-CORRECT; FARNELL 2426215
LOGO1: OSHW-LOGOM (NP); OSHW-LOGO-M
LOGO2: LOGO_TI-4MM (NP); LOGO_TI_4MM
LOGO3: LOGO_ST-4MM (NP); LOGO_ST_4MM
LOGO4: LOGO_HCD-4MM (NP); LOGO_HDC_4MM
LOGO5: LOGO_MICROSOFT-4MM (NP); LOGO_MS_4MM
LOGO6: LOGO_MICROPYTHON-8MM (NP); LOGO_MICROPYTHON_8MM
OUTLINE1: TILDA_MK3 (NP); TILDA_MKE_OUTLINE
Q1: DMMT5401; SOT26; FARNELL 1773583
Q2, Q6: CSD25402Q3A; Q3A; FARNELL 2501103
Q3, Q8: CSD13202Q2; Q2; FARNELL 2501084
Q4: DNP (CSD85301Q2); Q2_DUAL; FARNELL 2470183
R1: DNP; 0207/10
R2, R14, R18, R19: 0603/4k7/5%; C0603K-SMALL
R3, R4, R20, R27, R45: 0603/220k/5%; C0603K-SMALL
R5: 0603/4M7/5%; C0603K-SMALL
R6, R12: 0603/2k/5%; C0603K-SMALL
R7, R10, R32: 0603/0R; C0603K-SMALL
R8, R11: DNP; C0603K-SMALL
R9: 0603/1k/5%; C0603K-SMALL
R13, R16, R17: 0603/10k/5%; C0603K-SMALL
R15, R33: 0603/47k/5%; C0603K-SMALL
R21, R22: 0603/470k/5%; C0603K-SMALL
R26: 0603/120R/5%; C0603K-SMALL
R28, R29: DNP (0603/4M7/5%); C0603K-SMALL; FARNELL 2059694
R30, R31: DNP (0603/10k/5%); C0603K-SMALL
R44, R47, R48, R49: 0603/12R/5%; C0603K-SMALL; FARNELL 9331280
R50: DNP (0603/2k/5%); C0603K-SMALL
R51: DNP (0603/330/5%); C0603K-SMALL
S1, S7: 6x3; TACTILE-SWITCH-1101NE
S3, S4: SKPMAPE010; SKPMAPE010-COMBINED; FARNELL 1217769
S5: CUS-12TB; SWITCH-SPST-SMD-A; FARNELL 9575146
S8: DNP (6x3); TACTILE-SWITCH-1101NE
SG1: BUZZER-PKLCS1212E
SJ1: OTG (NP); SJ_2S-NO
SV2, SV3, SV4, SV5, SV6, SV7: (NP); 1X03
SW1: JOYSTICK; JOYSTICK_MULTICOMP_NOSILK; FARNELL 1316987
TP1, TP2, TP3, TP4, TP5, TP11, TP12, TP13, TP14, TP15, TP16, TP17, TP18, TP19, TP20, TP21: (NP); B1,27
U1: USD-SOCKET; 0011XAAX09X; FARNELL 2427719
U2: ER-TFT024-3 (NP); ER-TFT024-3
X3: ABS07-32.768KHZ-T; RESONATOR_EPSON_FC_145; FARNELL 2101347

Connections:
!CC_HIB: IC3.63 (PC6), IC6.4 (!HIB), TP5.TP
!CC_RST: IC3.2 (PE3), IC6.35 (!RESET), S8.P$1 (1), TP20.TP
!UART_CTS: IC6.51 (!UART_CTS), TP12.TP
!UART_RTS: IC6.44 (!UART_RTS), TP13.TP
+3V3: C5.1, C8.2, C11.2, C12.2, C17.2, C22.2, C25.1, C26.1, C27.1, C34.2, C35.1, C36.1, C37.2, C38.2, C39.2, C41.1, C42.1, C45.2, IC2.5 (VOS), IC3.11 (VDD1), IC3.28 (VDD3), IC3.50 (VDD), IC3.75 (VDD5), IC3.100 (VDD4), IC6.36 (VBAT_DCDC_ANA), IC6.37 (VBAT_DCDC_PA), IC6.40 (VBAT_DCDC_DIG), IC8.5 (VDDIO), IC8.8 (VDD), IC8.12 (CS), IC9.5 (VDD), IC9.6 (VDDIO), IC9.9 (SDO/SA1), IC9.10 (CS), J2.1 (LEDA), J2.40 (VDDI), J2.41 (VDDI), J2.42 (VCI), J3.1 (VCC), JP1.1, JP2.1, JP4.1 (VCC), L1.2, L3.1, LED4.C, OUTLINE1.3V3, R1.2, R7.1, R8.2, R18.1, R19.1, R30.1, R31.1, SW1.COM, U1.4 (VCC)
ADC_IN: IC3.35 (PB0), JP2.8
ADC_LIGHT: C13.2, IC3.36 (PB1), LED4.A, R5.1
ADC_VIN: C18.2, IC3.26 (PA3), R3.2, R4.1
ADC_X: IC3.17 (PC2), J2.46 (X-)
ADC_Y: IC3.18 (PC3), J2.47 (Y-)
BAT: C48.2, IC7.5 (BAT), R51.1
BOOT0/JOY_CEN: IC3.94 (BOOT0), IC3.97 (PE0), R33.2, SW1.CTR (CENT)
BTN_A: IC3.77 (PA15), S4.2, S4.B1 (2), S4.B2 (2)
BTN_B: IC3.58 (PD11), S3.2, S3.B1 (2), S3.B2 (2)
BTN_MENU: IC3.84 (PD3), S7.P$2 (2)
BUZZ: IC3.59 (PD12), R26.2
C1: C40.1, IC9.4 (C1)
CC_IRQ: IC3.3 (PE4), IC6.11 (IRQ)
CC_RESERVED: IC6.21 (RESERVED), R20.1
COUT: IC7.2 (COUT), Q4.5 (G), R28.1
DAC_OUT: IC3.30 (PA5), JP2.5
DFGFDG: C15.2, C16.2, IC3.21 (VREF+), IC3.22 (VDDA), L3.2
DOUT: IC7.3 (DOUT), Q4.2 (G), R29.1
DRDY: IC8.9 (INT2), IC9.8 (DRDY)
D_N: IC1.1 (IO1), IC3.70 (PA11), J1.D-
D_P: IC1.2 (IO2), IC3.71 (PA12), J1.D+
FET_OUT: LED1.K (C), OUTLINE1.FET, Q3.1 (D), Q3.2 (D), Q3.5 (D), Q3.6 (D), Q3.EP1 (D)
FORCE_AP: IC6.10 (FORCE_AP), R27.1, TP11.TP
FSMC_A23: IC3.1 (PE2), IC3.89 (PB3), J2.37 (D/CX(SCL)), TP4.TP
FS_VUSB: IC3.68 (PA9), R10.1
GND: C1.1, C2.1, C3.1, C4.-, C5.2, C6.2, C7.1, C8.1, C9.1, C10.1, C11.1, C12.1, C13.1, C15.1, C16.1, C17.1, C18.1, C19.1, C22.1, C23.1, C24.1, C25.2, C26.2, C27.2, C29.1, C33.1, C34.1, C35.2, C36.2, C37.1, C38.1, C39.1, C40.2, C41.2, C42.2, C45.1, D1.3 (VSS), IC1.3 (GND), IC2.2 (GND), IC2.3 (MODE), IC2.EP (GND), IC3.10 (VSS1), IC3.20 (VSSA/VREF-), IC3.27 (VSS2), IC3.74 (VSS3), IC3.99 (VSS4), IC4.3 (VSS), IC4.7 (ISET2), IC4.EP (VSS), IC6.1 (GND), IC6.2 (GND), IC6.16 (GND), IC6.27 (GND), IC6.28 (GND), IC6.30 (GND), IC6.32 (GND), IC6.38 (GND), IC6.43 (GND), IC6.55 (GND), IC6.56 (GND), IC6.57 (GND), IC6.58 (GND), IC6.59 (GND), IC6.60 (GND), IC6.61 (GND), IC6.62 (GND), IC6.63 (GND), IC8.1 (SDO/SA0), IC8.6 (GND), IC8.7 (GND), IC9.2 (GND), IC9.3 (GND), IC9.12 (GND), J1.GND, J1.SHIELD, J1.SHIELD@0 (SHIELD), J1.SHIELD@1 (SHIELD), J1.SHIELD@2 (SHIELD), J1.SHIELD@3 (SHIELD), J1.SHIELD@5 (SHIELD), J2.6 (IM0), J2.11 (VSYNC), J2.12 (HSYNC), J2.13 (DOTCLK), J2.14 (DE), J2.15 (DB17), J2.16 (DB16), J2.17 (DB15), J2.18 (DB14), J2.19 (DB13), J2.20 (DB12), J2.21 (DB11), J2.22 (DB10), J2.23 (DB9), J2.24 (DB8), J2.43 (GND), J2.48 (GND), J2.49 (GND), J2.50 (GND), J3.3 (GND1), J3.5 (GND2), J3.9 (GNDD), JP1.11, JP2.11, JP4.5 (GND), LED2.C, LED3.C, OUTLINE1.GND, Q3.4 (S), Q3.EP2 (S), Q4.4 (S), Q8.4 (S), Q8.EP2 (S), R4.2, R5.2, R6.2, R9.2, R11.1, R13.2, R15.2, R16.2, R17.2, R20.2, R22.2, R27.2, R28.2, R32.1, R33.1, R50.2, S1.P$2 (2), S3.1, S3.A1 (1), S3.A2 (1), S4.1, S4.A1 (1), S4.A2 (1), S5.2, S7.P$1 (1), S8.P$2 (2), SG1.P$2 (2), SV2.1, SV3.1, SV4.1, SV5.1, SV6.1, SV7.1, U1.6 (GND), U1.GND (SHIELD), U1.GND1 (SHIELD), U1.GND2 (SHIELD), U1.GND3 (SHIELD)
I2C_SCL: IC3.95 (PB8), JP2.4, OUTLINE1.SCL
I2C_SDA: IC3.96 (PB9), JP2.3, OUTLINE1.SDA
IMU_IRQ2: IC3.7 (PC13), IC8.4 (INT1)
IMU_SCL: IC3.15 (PC0), IC8.13 (SCL), R19.2, TP19.TP
IMU_SDA: IC3.16 (PC1), IC8.14 (SDA), R18.2, TP18.TP
JOY_DOWN: IC3.56 (PD9), SW1.D (DOWN)
JOY_LEFT: IC3.87 (PD6), SW1.C (LEFT)
JOY_RIGHT: IC3.57 (PD10), SW1.B (RIGHT)
JOY_UP: IC3.55 (PD8), SW1.A (UP)
LCD0: IC3.61 (PD14), J2.32 (DB0), TP1.TP
LCD1: IC3.62 (PD15), J2.31 (DB1)
LCD2: IC3.81 (PD0), J2.30 (DB2)
LCD3: IC3.82 (PD1), J2.29 (DB3)
LCD4: IC3.38 (PE7), J2.28 (DB4)
LCD5: IC3.39 (PE8), J2.27 (DB5)
LCD6: IC3.40 (PE9), J2.26 (DB6)
LCD7: IC3.41 (PE10), J2.25 (DB7)
LCD_!RST: IC3.60 (PD13), J2.10 (RESET)
LCD_CS: IC3.88 (PD7), J2.38 (CSX)
LCD_MODE: IC3.5 (PE6), J2.7 (IM1), J2.8 (IM2), J2.9 (IM3)
LCD_RD: IC3.85 (PD4), J2.35 (RD), TP2.TP
LCD_WRX: IC3.86 (PD5), J2.36 (WRX(D/CX)), TP3.TP
LED1: IC3.46 (PE15), R12.2
LED2: IC3.43 (PE12), R14.2
LEDK1: J2.2 (LEDK1), R47.2
LEDK2: J2.3 (LEDK2), R48.2
LEDK3: J2.4 (LEDK3), R49.2
LEDK4: J2.5 (LEDK4), R44.2
unnamed: Q4.3 (D), Q4.6 (D), Q4.EP1 (D), Q4.EP2 (D)
unnamed: R26.1, SG1.P$1 (1)
unnamed: C19.2, IC3.19 (VDD2), R8.1
unnamed: Q1.4 (C2), Q2.4 (G), R15.1
unnamed: Q1.1 (C1), Q1.2 (B1), Q1.3 (B2), R16.1
unnamed: LED5.C, R2.2
unnamed: IC4.8 (!CHG), R2.1
unnamed: IC4.4 (PRETERM), R6.1
unnamed: IC4.2 (ISET), R9.1
unnamed: IC4.9 (TS), R13.1
unnamed: D1.2 (DOUT), SV2.3
unnamed: C7.2, IC1.5 (VCC), J1.VBUS, L2.1
unnamed: D2.C, SJ1.1
unnamed: ANT1.P$1, IC6.31 (RF_BG)
unnamed: C10.2, IC3.49 (VSS)
unnamed: LED3.A, R14.1
unnamed: LED2.A, R12.1
unnamed: LED1.A, R1.1
unnamed: Q8.1 (D), Q8.2 (D), Q8.5 (D), Q8.6 (D), Q8.EP1 (D), R44.1, R47.1, R48.1, R49.1
NRST: IC3.14 (!NRST), J3.10 (NRST), JP4.3 (RST), S1.P$1 (1)
OCS32_IN: C23.2, IC3.8 (PC14/OSC32_IN), X3.P$1 (1)
OCS32_OUT: C24.2, IC3.9 (PC15/OSC32_OUT), X3.P$2 (2)
PB2: IC3.37 (PB2), JP1.7, R11.2
SCX: IC8.3 (SCX), IC9.1 (SCL/SPC), R31.2
SDIO_CLK: IC3.80 (PC12), U1.5 (CLK)
SDIO_CMD: IC3.83 (PD2), U1.3 (CMD)
SDIO_D0: IC3.65 (PC8), U1.7 (DAT0)
SDIO_D1: IC3.66 (PC9), U1.8 (DAT1)
SDIO_D2: IC3.78 (PC10), U1.1 (DAT2)
SDIO_D3: IC3.79 (PC11), U1.2 (DAT3)
SDIO_SW: IC3.67 (PA8), U1.CD (DET)
SDX: IC8.2 (SDX), IC9.11 (SDA/SDI/SDO), R30.2
SOP2: IC6.23 (SOP2), R17.1
SPI1_MISO: IC3.31 (PA6), IC6.7 (SPI_DOUT)
SPI1_MOSI: IC3.32 (PA7), IC6.6 (SPI_DIN)
SPI1_NSS: IC3.29 (PA4), IC6.8 (!SPI_CS)
SPI1_SCK: IC3.44 (PE13), IC6.5 (SPI_CLK)
SPI2_CLK: IC3.47 (PB10), JP1.8
SPI2_MISO: IC3.53 (PB14), JP1.9
SPI2_MOSI: IC3.54 (PB15), JP1.10
SPI2_NSS: IC3.51 (PB12), JP1.6
SPI3_MISO: IC3.90 (PB4), J2.33 (SDO)
SPI3_MOSI: IC3.91 (PB5), J2.34 (SDI)
SW: IC2.7 (SW), L1.1
SWCLK: IC3.76 (PA14), J3.4 (SWCLK), JP4.4 (SWCLK)
SWDAT: IC3.72 (PA13), J3.2 (SWDAT), JP4.2 (SWDAT)
TEAR: IC3.4 (PE5), J2.39 (TE), TP21.TP
TEST_58: IC6.48 (TEST_58), TP14.TP
TEST_59: IC6.49 (TEST_59), TP15.TP
TEST_60: IC6.50 (TEST_60), TP16.TP
TEST_62: IC6.52 (TEST_62), TP17.TP
TIM1_CH2: IC3.42 (PE11), JP2.9
TIM1_CH4: IC3.45 (PE14), JP2.10
TIM2_CH1: IC3.23 (PA0), JP1.2, OUTLINE1.CH4, SV3.3
TIM2_CH2: IC3.24 (PA1), JP1.3, OUTLINE1.CH3, SV5.3
TIM2_CH3: IC3.25 (PA2), JP1.4, OUTLINE1.CH2, SV6.3
TIM2_CH4: C9.2, IC3.48 (VCAP1), JP1.5, OUTLINE1.CH1, SV4.3
TIM8_CH2: IC3.64 (PC7), Q3.3 (G)
TIM17_CH1: IC3.98 (PE1), Q8.3 (G)
T_X: IC3.12 (PH0/OCS_IN), J2.44 (X+)
T_Y: IC3.13 (PH1/OSC_OUT), J2.45 (Y+)
USART1_RX: IC3.93 (PB7), IC6.46 (UART1_TX), SV7.3
USART1_TX: IC3.92 (PB6), IC6.47 (UART1_RX), SV7.2
USART3_RX: IC3.34 (PC5), JP2.7
USART3_TX: IC3.33 (PC4), JP2.6
USB_ID: IC1.4 (IO3), IC3.69 (PA10), J1.ID (USBID)
V-: IC7.6 (V-), R50.1
VABT_SWTICHED: D2.A, Q1.6 (E1), Q2.1 (D), Q2.2 (D), Q2.3 (D), Q6.1 (D), Q6.2 (D), Q6.3 (D)
VACP2: C29.2, IC3.73 (VCAP2), R7.2
VBAT: C3.2, IC4.10 (OUT), JP3.2, Q6.5 (S), Q6.6 (S), Q6.7 (S), Q6.8 (S), Q6.EP (S), R21.2, R45.1, R51.2
VBATT_IN: C33.2, IC3.6 (VBAT), R21.1, R22.1
VBAT_NEG: C48.1, IC7.4 (VSS), JP3.1, Q4.1 (S), R29.2, R32.2
VBAT_SWITCH_CONTROL: Q6.4 (G), R45.2, S5.3 (S)
VBUS: C1.2, C4.+, D3.A, IC4.1 (IN), L2.2, LED5.A, R10.2, SJ1.2
V_UNREG: C2.2, C6.1, D1.1 (VDD), D3.C, IC2.1 (EN), IC2.8 (VIN), JP2.2, OUTLINE1.VBATT, Q1.5 (E2), Q2.5 (S), Q2.6 (S), Q2.7 (S), Q2.8 (S), Q2.EP (S), R3.1, SV2.2, SV3.2, SV4.2, SV5.2, SV6.2
WS2812: D1.4 (DIN), IC3.52 (PB13)

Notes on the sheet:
Headers
LCD Screen
STM Power
Port F
JTAG SWD
Port A
Port B
Port C
Port D
close for OTG
depends on led
MicroSD Card
Servo / WS2812 Headers
Port E
USB OTG
Battery Charger
LEDs
ADC Inputs
LCD_MODE 0: parallel; 1: serial
(PARALLEL)
(NOE)
(NWE)
688-SCHA4B0419
F4x1
F4x5/7
C19
pin 19
dnp
100n
2u2
C10
EXTI List
0 1 2 3 4 5 6 7 8 9 10 11 12 13 14 15
JOY CENTRE
TEAR
JOY_RIGHT
CC_IRQ
JOY_DWN
MOM RIGHT
MOM DWN

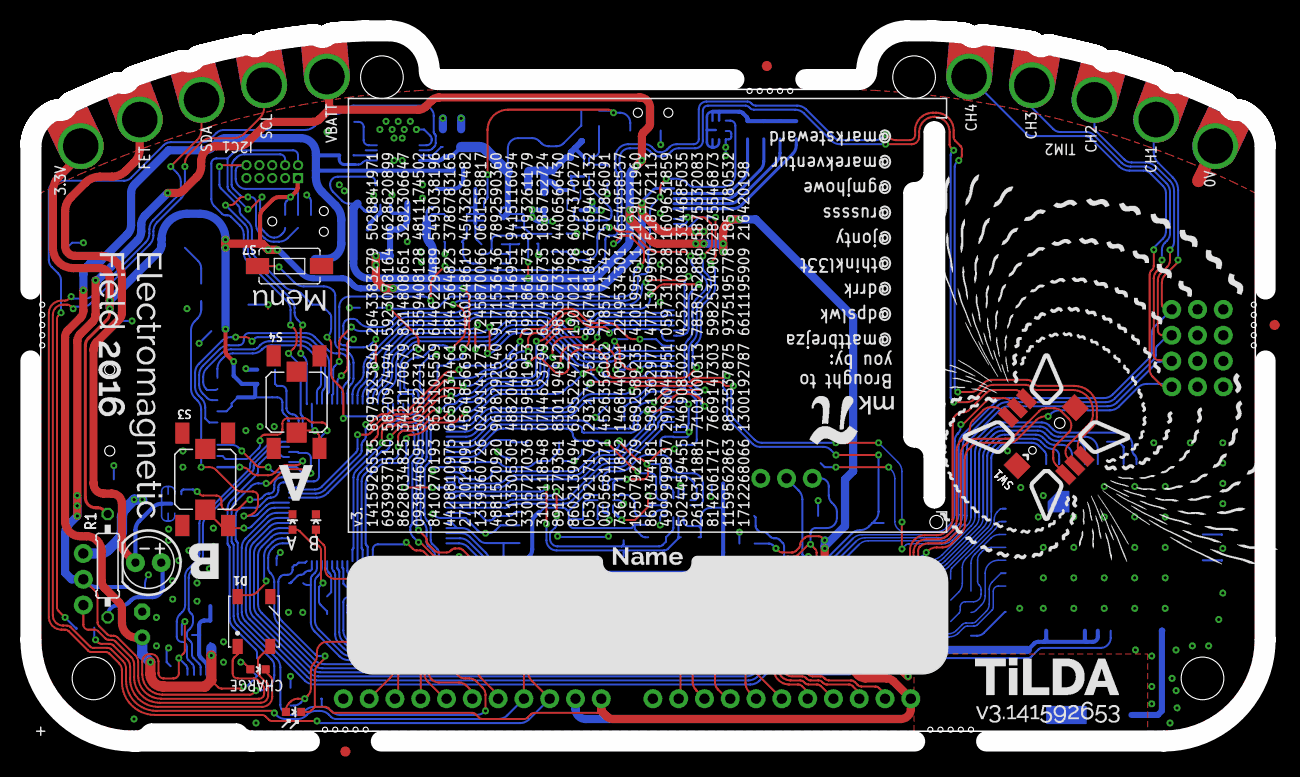
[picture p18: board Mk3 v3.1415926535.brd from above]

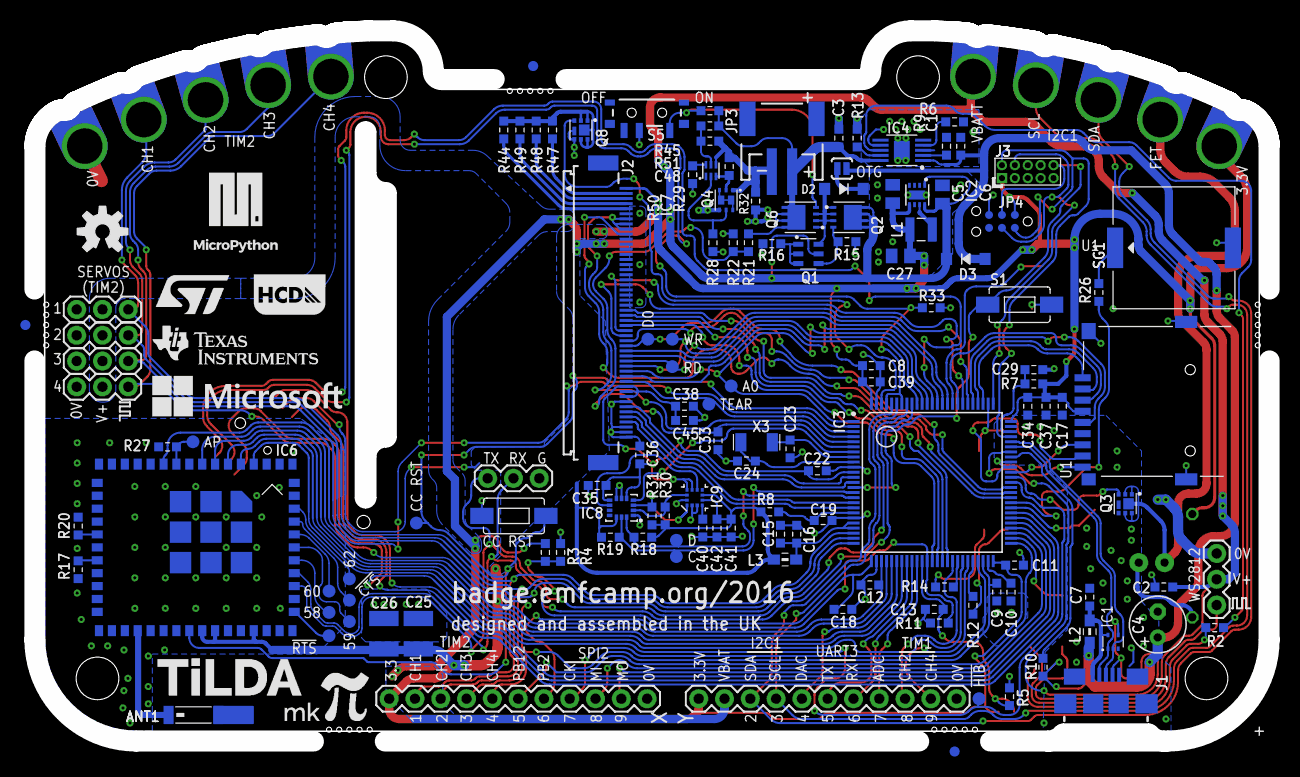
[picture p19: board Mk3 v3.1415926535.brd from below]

Board: 2 copper layers, 121.6 x 70.0 mm, 156 parts (139 on the bottom side), 135 nets.

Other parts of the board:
ARTWORK1: ARTWORK_MKπ_BACK; TILDA_MKπ_ARTWORK_BACK
ARTWORK2: ARTWORK_MKπ_FRONT; TILDA_MKπ_ARTWORK_FRONT

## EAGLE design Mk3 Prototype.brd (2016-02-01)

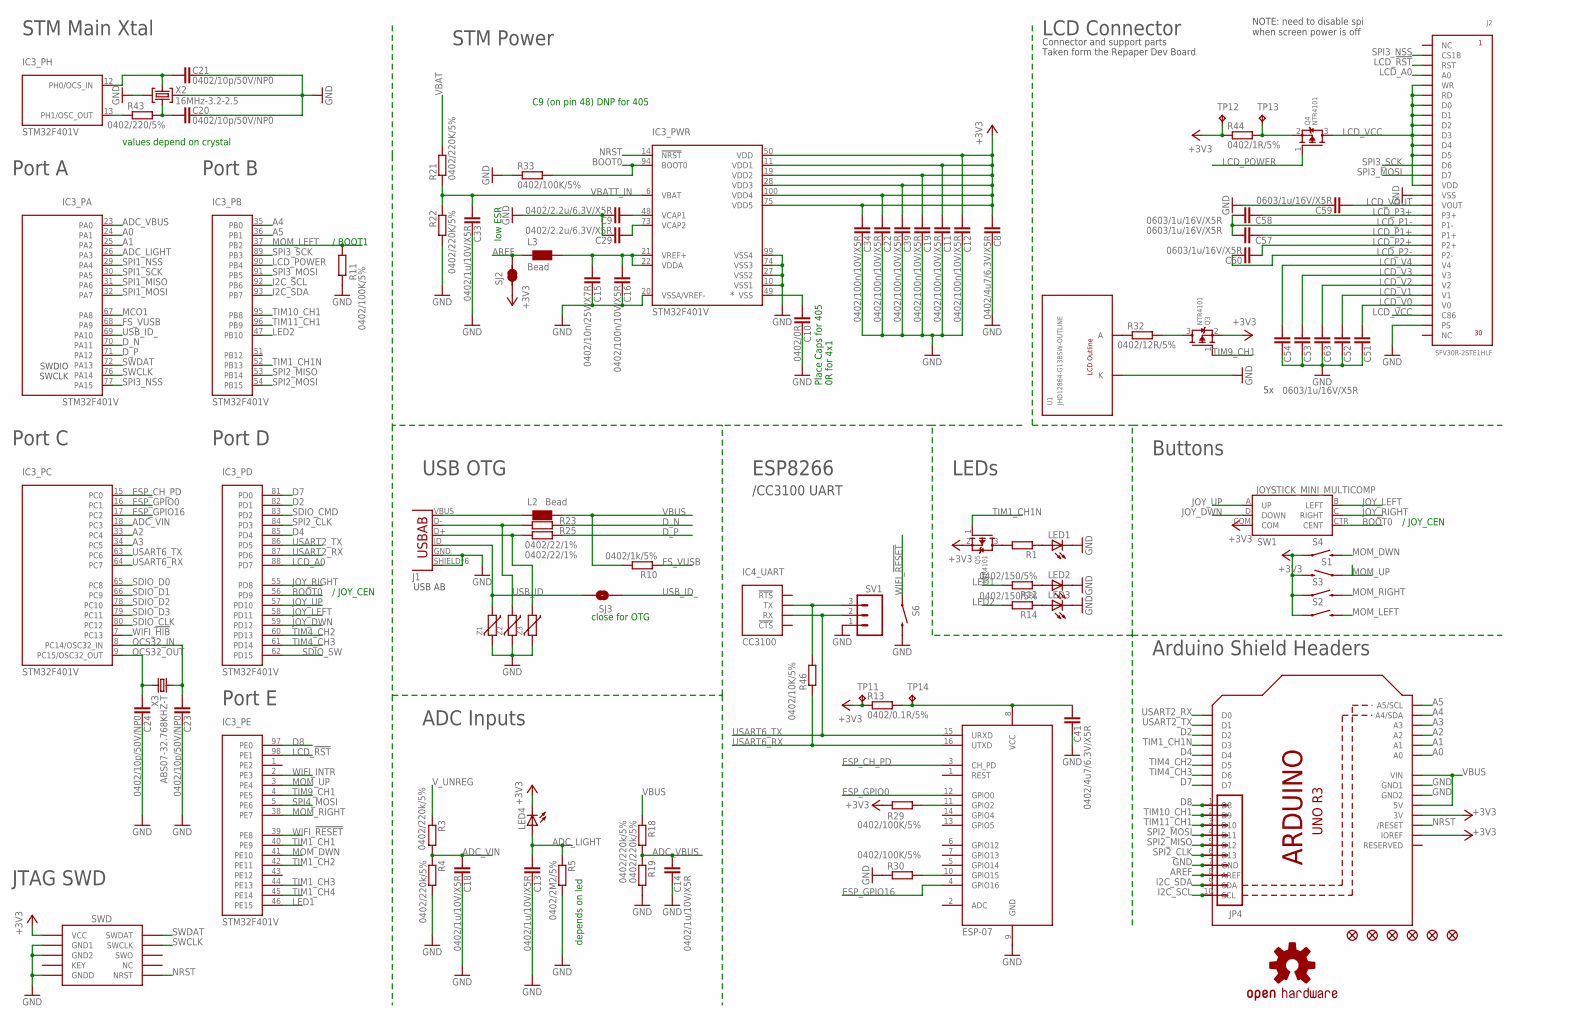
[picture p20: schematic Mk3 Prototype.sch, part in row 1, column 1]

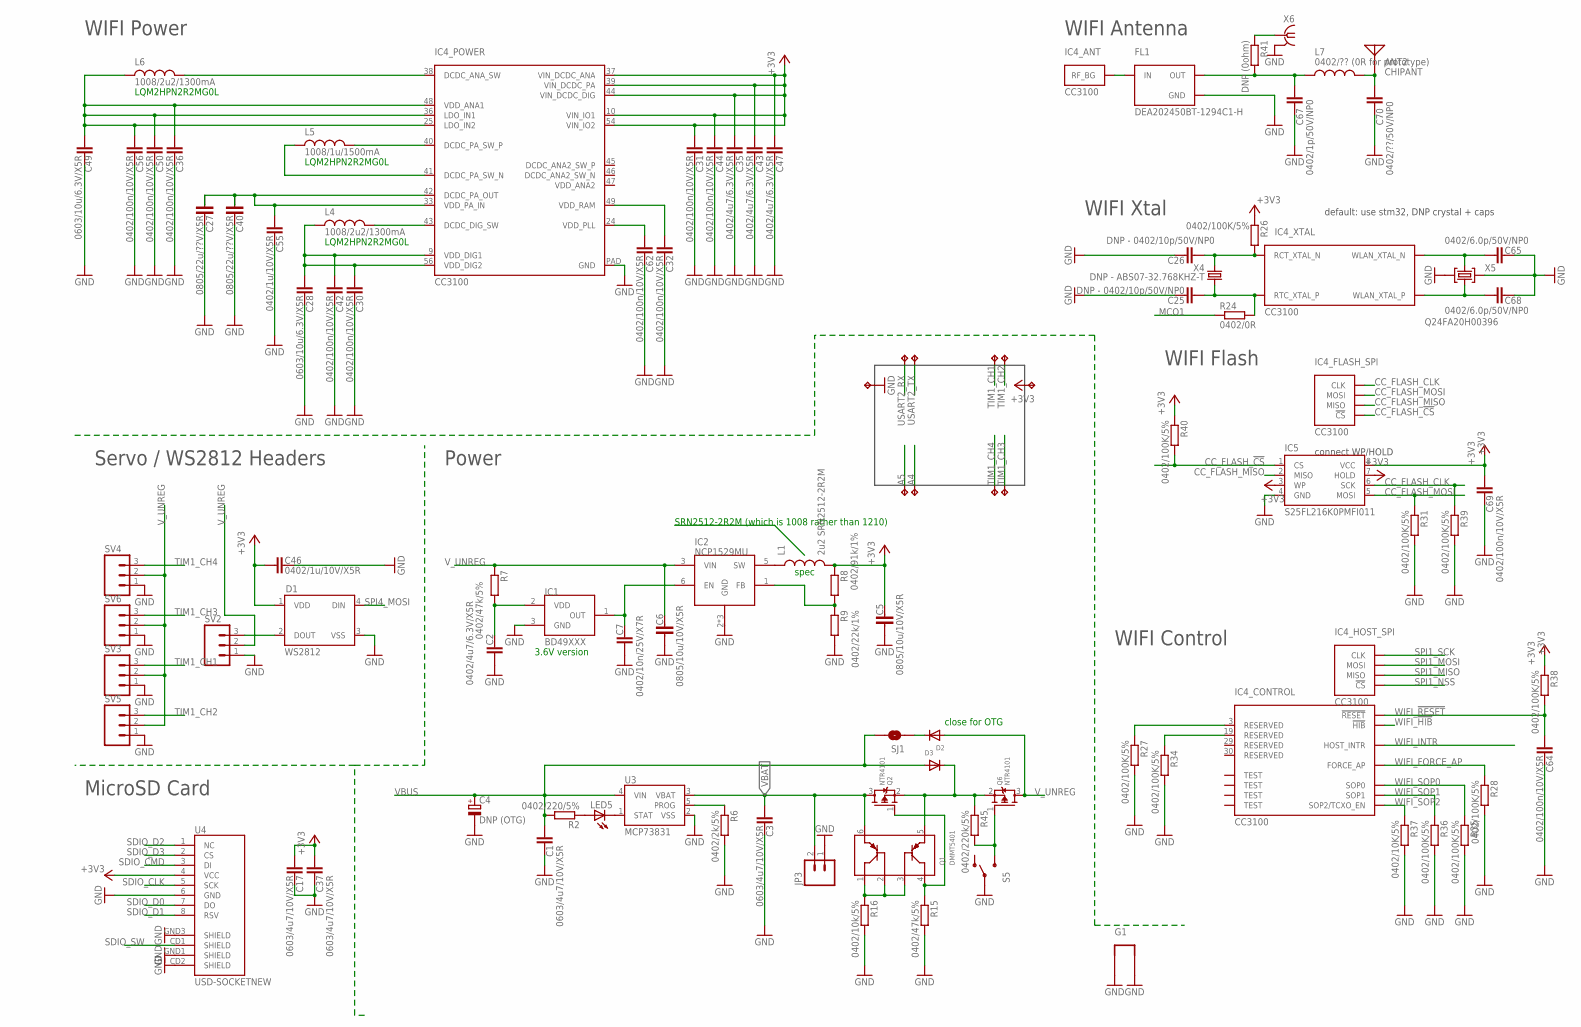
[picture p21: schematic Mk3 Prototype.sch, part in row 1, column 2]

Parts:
ANT2: CHIPANT; 2450AT42A100
C1: 0603/4u7/10V/X5R; C0805K
C2, C8, C35, C41, C43, C47: 0402/4u7/6.3V/X5R; C0402-SMALLER
C3, C17, C37: 0603/4u7/10V/X5R; C0603K-SMALL
C4: DNP (OTG); E2,5-6
C5, C6: 0805/10u/10V/X5R; C0805-N
C7, C15: 0402/10n/25V/X7R; C0402-SMALLER
C9, C29: 0402/2.2u/6.3V/X5R; C0402-SMALLER
C10: 0402/0R; C0402-SMALLER
C11, C12, C16, C19, C22, C30, C31, C32, C34, C36, C39, C42, C44, C50, C56, C62, C64, C69: 0402/100n/10V/X5R; C0402-SMALLER
C13, C14, C18, C33, C46, C55: 0402/1u/10V/X5R; C0402-SMALLER
C20, C21, C23, C24: 0402/10p/50V/NP0; C0402-SMALLER
C25, C26: DNP - 0402/10p/50V/NP0; C0402-SMALLER
C27, C40: 0805/22u/??V/X5R; C0805-N
C28, C49: 0603/10u/6.3V/X5R; C0603K-SMALL
C51, C52, C53, C54, C57, C58, C59, C60, C63: 0603/1u/16V/X5R; C0603K-SMALL
C65, C68: 0402/6.0p/50V/NP0; C0402-SMALLER
C67: 0402/1p/50V/NP0; C0402-SMALLER
C70: 0402/??/50V/NP0; C0402-SMALLER
D1: WS2812B
D2, D3: DIODESOD-323F; SOD-323F
FID1, FID2, FID3, FID4, FID5, FID6: FIDUCIAL1X2.5-STOP; FIDUCIAL-1X2.5-STOP
FL1: DEA202450BT-1294C1-H; DEA202450BT
G1: GND-LOOP
IC1: BD49XXX; SSOP5
IC2: NCP1529MU; DFN6
IC3: STM32F401V; TQFP100
IC4: CC3100; VQFN-64
IC5: S25FL216K0PMFI011; SO08-EIAJ
J1: ZX62-AB-5PA(11); USB-AB-MICRO-SMD_LWK
J2: SFV30R-2STE1HLF
J3: SWD_SHROUD; SWD_PTH_SHROUD
JP3: M02-JST-2MM-SMT; JST-2-SMD
JP4: M10NOSILK; 1X10-NOSILK
L1: 2u2 SRN2512-2R2M; 1210
L2, L3: Bead; WUERTH-0805
L4, L6: 1008/2u2/1300mA; 1008
L5: 1008/1u/1500mA; 1008
L7: 0402/?? (0R for prototype); L0402
LED1: LED5MM
LED2, LED3, LED4, LED5: LED0603-CORRECT; LED-0603-CORRECT
LOGO1: OSHW-LOGOM; OSHW-LOGO-M
Q1: DMMT5401; SOT26
Q2, Q3, Q4, Q5, Q6: NTR4101; SOT23-R
R1: R-EU_0207/10; 0207/10
R2, R43: 0402/220/5%; R0402-SMALLER
R3, R4, R18, R19, R45: 0402/220k/5%; R0402-SMALLER
R5: 0402/2M2/5%; R0402-SMALLER
R6: 0402/2k/5%; R0402-SMALLER
R7, R15: 0402/47k/5%; R0402-SMALLER
R8: 0402/91k/1%; R0402-SMALLER
R9: 0402/22k/1%; R0402-SMALLER
R10: 0402/1k/5%; R0402-SMALLER
R11, R26, R27, R28, R29, R30, R31, R33, R34, R35, R36, R38, R39, R40: 0402/100K/5%; R0402-SMALLER
R12, R14: 0402/150/5%; R0402-SMALLER
R13: 0402/0.1R/5%; R0402-SMALLER
R16: 0402/10k/5%; R0402-SMALLER
R21, R22: 0402/220K/5%; R0402-SMALLER
R23, R25: 0402/22/1%; R0402-SMALLER
R24: 0402/0R; R0402-SMALLER
R32: 0402/12R/5%; R0402-SMALLER
R37, R46: 0402/10K/5%; R0402-SMALLER
R41: DNP (0ohm); R0402-SMALLER
R44: 0402/1R/5%; R0402-SMALLER
S1, S2, S3, S4: SWITCH-MOMENTARY-2; TACTILE_SWITCH_TALL
S5: SWITCH-SPST-SMD-A
S6: SWITCH-MOMENTARY-2SMD-1101NE; TACTILE-SWITCH-1101NE
SJ1, SJ3: JUMPER-PAD-2-NOYES_SILK; PAD-JUMPER-2-NO_YES_SILK
SJ2: SOLDERJUMPERTRACE; SJ_2S-TRACE
SV1, SV2, SV3, SV4, SV5, SV6: M03PTH; 1X03
SW1: JOYSTICK_MINI_MULTICOMP; JOYSTICK_MULTICOMP
TP1, TP2, TP3, TP4, TP5, TP6, TP7, TP8, TP9, TP10: TP4MM; 4MMEDGE
TP11, TP12, TP13, TP14: TPB1,27; B1,27
U1: JHD12864-G13BSW-OUTLINE
U2: ARDUINOR3-NODIM
U3: MCP73831; SOT23-5
U4: USD-SOCKETNEW; MICRO-SD-SOCKET-PP
X1: ESP-07
X2: 16MHz-3.2-2.5; CRYSTAL-3.2-2.5
X3: ABS07-32.768KHZ-T; RESONATOR_EPSON_FC_145
X4: DNP - ABS07-32.768KHZ-T; RESONATOR_EPSON_FC_145
X5: Q24FA20H00396; CRYSTAL-2.5X2.0
X6: MC-921
Z1, Z2, Z3: VARISTORCN0603; CT/CN0603

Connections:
+3V3: C5.1, C8.2, C11.2, C12.2, C17.2, C19.2, C22.2, C31.2, C34.2, C35.2, C37.2, C39.2, C43.2, C44.2, C46.2, C47.2, C69.2, D1.1 (VDD), IC3.11 (VDD1), IC3.19 (VDD2), IC3.28 (VDD3), IC3.50 (VDD), IC3.75 (VDD5), IC3.100 (VDD4), IC4.10 (VIN_IO1), IC4.37 (VIN_DCDC_ANA), IC4.39 (VIN_DCDC_PA), IC4.44 (VIN_DCDC_DIG), IC4.54 (VIN_IO2), IC5.3 (WP), IC5.7 (HOLD), IC5.8 (VCC), J3.1 (VCC), L1.2, LED4.C, Q3.2 (S), Q5.2 (S), R8.1, R13.1, R26.1, R29.1, R38.1, R40.1, R44.1, S1.B2 (2), S2.A2 (1), S3.A2 (1), S4.A2 (1), SJ2.1, SW1.COM, TP6.P$1, TP11.TP, TP12.TP, U2.3V, U2.IOREF, U4.4 (VCC)
A0: IC3.24 (PA1), U2.A0
A1: IC3.25 (PA2), U2.A1
A2: IC3.33 (PC4), U2.A2
A3: IC3.34 (PC5), U2.A3
A4: IC3.35 (PB0), TP8.P$1, U2.A4 (A4/SDA)
A5: IC3.36 (PB1), TP7.P$1, U2.A5 (A5/SCL)
ADC_LIGHT: C13.2, IC3.26 (PA3), LED4.A, R5.1
ADC_VBUS: C14.2, IC3.23 (PA0), R18.2, R19.1
ADC_VIN: C18.2, IC3.18 (PC3), R3.2, R4.1
ANT: ANT2.P$1, C70.1, L7.2
AREF: JP4.8, L3.1, SJ2.2, U2.AREF
BOOT0: IC3.56 (PD9), IC3.94 (BOOT0), R33.2, SW1.CTR (CENT)
CC_FLASH_!CS: IC4.14 (!CS), IC5.1 (CS), R40.2
CC_FLASH_CLK: IC4.11 (CLK), IC5.6 (SCK), R39.1
CC_FLASH_MISO: IC4.13 (MISO), IC5.2 (MISO)
CC_FLASH_MOSI: IC4.12 (MOSI), IC5.5 (MOSI), R31.1
CHARGING: LED5.C, U3.1 (STAT)
D2: IC3.82 (PD1), U2.D2
D4: IC3.85 (PD4), U2.D4
D7: IC3.81 (PD0), U2.D7
D8: IC3.97 (PE0), JP4.1, U2.D8
DFGFDG: C15.2, C16.2, IC3.21 (VREF+), IC3.22 (VDDA), L3.2
D_N: IC3.70 (PA11), R23.1
D_P: IC3.71 (PA12), R25.1
ESP_CH_PD: IC3.15 (PC0), X1.3 (CH_PD)
ESP_GPIO0: IC3.16 (PC1), X1.12 (GPIO0)
ESP_GPIO16: IC3.17 (PC2), X1.4 (GPIO16)
FS_VUSB: IC3.68 (PA9), R10.1
GND: C1.1, C2.2, C3.1, C4.-, C5.2, C6.2, C7.2, C8.1, C9.1, C10.1, C11.1, C12.1, C13.1, C14.1, C15.1, C16.1, C17.1, C18.1, C19.1, C20.1, C21.1, C22.1, C23.1, C24.1, C25.1, C26.1, C27.1, C28.1, C29.1, C30.1, C31.1, C32.1, C33.1, C34.1, C35.1, C36.1, C37.1, C39.1, C40.1, C41.1, C42.1, C43.1, C44.1, C46.1, C47.1, C49.1, C50.1, C51.1, C52.1, C53.1, C54.1, C55.1, C56.1, C59.1, C62.1, C63.1, C64.1, C65.1, C67.2, C68.1, C69.1, C70.2, D1.3 (VSS), FL1.GND@2 (GND), FL1.GND@4 (GND), G1.P$3 (1), G1.P$4 (2), IC1.3 (GND), IC2.2 (GND), IC2.4 (GND), IC2.EP (GND), IC3.10 (VSS1), IC3.20 (VSSA/VREF-), IC3.27 (VSS2), IC3.74 (VSS3), IC3.99 (VSS4), IC4.PAD (GND), IC5.4 (GND), J1.GND, J1.SHIELD, J1.SHIELD@0 (SHIELD), J1.SHIELD@1 (SHIELD), J1.SHIELD@2 (SHIELD), J1.SHIELD@3 (SHIELD), J1.SHIELD@5 (SHIELD), J2.16 (VSS), J2.29 (PS), J2.M1 (VSS), J2.M2 (VSS), J3.3 (GND1), J3.5 (GND2), J3.9 (GNDD), JP3.1, JP4.7, LED1.K (C), LED2.C, LED3.C, R4.2, R5.2, R6.2, R9.2, R11.1, R15.2, R16.2, R19.2, R22.2, R27.2, R28.2, R30.1, R31.2, R33.1, R34.2, R35.2, R36.2, R37.2, R39.2, S5.2, S6.2, SV1.1, SV2.1, SV3.1, SV4.1, SV5.1, SV6.1, TP5.P$1, U1.K, U2.GND, U2.GND1, U2.GND2, U3.2 (VSS), U4.6 (GND), U4.CD2 (SHIELD), U4.GND1 (SHIELD), U4.GND3 (SHIELD), X1.9 (GND), X2.2 (GND), X2.4 (GND), X5.2 (GND), X5.4 (GND), X6.2@1 (GND), X6.2@2 (GND), Z1.2, Z2.2, Z3.2
I2C_SCL: IC3.92 (PB6), JP4.10, U2.SCL
I2C_SDA: IC3.93 (PB7), JP4.9, U2.SDA
JOY_DWN: IC3.59 (PD12), SW1.D (DOWN)
JOY_LEFT: IC3.58 (PD11), SW1.B (LEFT)
JOY_RIGHT: IC3.55 (PD8), SW1.C (RIGHT)
JOY_UP: IC3.57 (PD10), SW1.A (UP)
LCD_!RST: IC3.98 (PE1), J2.3 (RST)
LCD_A0: IC3.88 (PD7), J2.4 (A0)
LCD_P1+: C57.2, J2.20 (P1+)
LCD_P1-: C57.1, C58.1, J2.19 (P1-)
LCD_P2+: C60.2, J2.21 (P2+)
LCD_P2-: C60.1, J2.22 (P2-)
LCD_P3+: C58.2, J2.18 (P3+)
LCD_POWER: IC3.90 (PB4), Q4.1 (G)
LCD_V0: C51.2, J2.27 (V0)
LCD_V1: C52.2, J2.26 (V1)
LCD_V2: C63.2, J2.25 (V2)
LCD_V3: C53.2, J2.24 (V3)
LCD_V4: C54.2, J2.23 (V4)
LCD_VCC: J2.5 (WR), J2.6 (RD), J2.7 (D0), J2.8 (D1), J2.9 (D2), J2.10 (D3), J2.11 (D4), J2.12 (D5), J2.15 (VDD), J2.28 (C86), Q4.3 (D)
LCD_VOUT: C59.2, J2.17 (VOUT)
LED1: IC3.46 (PE15), R12.2
LED2: IC3.47 (PB10), R14.2
MCO1: IC3.67 (PA8), R24.1
MOM_DWN: IC3.41 (PE10), S4.B2 (2)
MOM_LEFT: IC3.37 (PB2), R11.2, S2.B2 (2)
MOM_RIGHT: IC3.38 (PE7), S3.B2 (2)
MOM_UP: IC3.3 (PE4), S1.A2 (1)
unnamed: R32.1, U1.A
unnamed: C67.1, FL1.OUT, L7.1, R41.2
unnamed: FL1.IN, IC4.31 (RF_BG)
unnamed: C9.2, IC3.48 (VCAP1)
unnamed: C26.2, IC4.52 (RCT_XTAL_N), R26.2, X4.P$1 (1)
unnamed: Q1.4 (C2), Q2.1 (G), R15.1
unnamed: Q1.1 (C1), Q1.2 (B1), Q1.3 (B2), R16.1
unnamed: C65.2, IC4.22 (WLAN_XTAL_N), X5.3 (C2)
unnamed: C68.2, IC4.23 (WLAN_XTAL_P), X5.1 (C1)
unnamed: IC4.3 (RESERVED), R27.1
unnamed: IC4.19 (RESERVED), R34.1
unnamed: C7.1, IC1.1 (OUT), IC2.6 (EN)
unnamed: IC2.1 (FB), R8.2, R9.1
unnamed: D3.C, Q1.5 (E2), Q2.2 (S), Q6.2 (S), R45.1
unnamed: IC4.38 (DCDC_ANA_SW), L6.2
unnamed: C27.2, C40.2, C55.2, IC4.33 (VDD_PA_IN), IC4.42 (DCDC_PA_OUT)
unnamed: C36.2, C49.2, C50.2, C56.2, IC4.25 (LDO_IN2), IC4.36 (LDO_IN1), IC4.48 (VDD_ANA1), L6.1
unnamed: IC4.43 (DCDC_DIG_SW), L4.2
unnamed: C62.2, IC4.24 (VDD_PLL)
unnamed: D1.2 (DOUT), SV2.3
unnamed: C28.2, C30.2, C42.2, IC4.9 (VDD_DIG1), IC4.56 (VDD_DIG2), L4.1
unnamed: IC4.40 (DCDC_PA_SW_P), L5.2
unnamed: IC4.41 (DCDC_PA_SW_N), L5.1
unnamed: C32.2, IC4.49 (VDD_RAM)
unnamed: IC2.5 (SW), L1.1
unnamed: J1.VBUS, L2.1
unnamed: D2.C, SJ1.1
unnamed: C21.2, IC3.12 (PH0/OCS_IN), X2.3 (C2)
unnamed: C25.2, IC4.51 (RTC_XTAL_P), R24.2, X4.P$2 (2)
unnamed: C20.2, R43.2, X2.1 (C1)
unnamed: R6.1, U3.5 (PROG)
unnamed: LED5.A, R2.1
unnamed: C10.2, IC3.49 (VSS)
unnamed: C29.2, IC3.73 (VCAP2)
unnamed: R29.2, X1.11 (GPIO2)
unnamed: IC4.55 (TX), R46.2, SV1.3
unnamed: IC3.13 (PH1/OSC_OUT), R43.1
unnamed: R30.2, X1.10 (GPIO15)
unnamed: R41.1, X6.1
unnamed: LED3.A, R14.1
unnamed: LED2.A, R12.1
unnamed: Q4.2 (S), R44.2, TP13.TP
unnamed: Q6.1 (G), R45.2, S5.3 (S)
unnamed: C2.1, IC1.2 (VDD), R7.2
unnamed: Q3.3 (D), R32.2
unnamed: LED1.A, R1.1
unnamed: Q5.3 (D), R1.2
NRST: IC3.14 (!NRST), J3.10 (NRST), U2.RESET (/RESET)
OCS32_IN: C23.2, IC3.8 (PC14/OSC32_IN), X3.P$1 (1)
OCS32_OUT: C24.2, IC3.9 (PC15/OSC32_OUT), X3.P$2 (2)
SDIO_CLK: IC3.80 (PC12), U4.5 (SCK)
SDIO_CMD: IC3.83 (PD2), U4.3 (DI)
SDIO_D0: IC3.65 (PC8), U4.7 (DO)
SDIO_D1: IC3.66 (PC9), U4.8 (RSV)
SDIO_D2: IC3.78 (PC10), U4.1 (NC)
SDIO_D3: IC3.79 (PC11), U4.2 (CS)
SDIO_SW: IC3.62 (PD15), U4.CD1 (SHIELD)
SPI1_MISO: IC3.31 (PA6), IC4.7 (MISO)
SPI1_MOSI: IC3.32 (PA7), IC4.6 (MOSI)
SPI1_NSS: IC3.29 (PA4), IC4.8 (!CS)
SPI1_SCK: IC3.30 (PA5), IC4.5 (CLK)
SPI2_CLK: IC3.84 (PD3), JP4.6, U2.D13
SPI2_MISO: IC3.53 (PB14), JP4.5, U2.D12
SPI2_MOSI: IC3.54 (PB15), JP4.4, U2.D11
SPI3_MOSI: IC3.91 (PB5), J2.14 (D7)
SPI3_NSS: IC3.77 (PA15), J2.2 (CS1B)
SPI3_SCK: IC3.89 (PB3), J2.13 (D6)
SPI4_MOSI: D1.4 (DIN), IC3.5 (PE6)
SWCLK: IC3.76 (PA14), J3.4 (SWCLK)
SWDAT: IC3.72 (PA13), J3.2 (SWDAT)
TIM1_CH1: IC3.40 (PE9), SV3.3, TP3.P$1
TIM1_CH1N: IC3.52 (PB13), Q5.1 (G), U2.D3
TIM1_CH2: IC3.42 (PE11), SV5.3, TP4.P$1
TIM1_CH3: IC3.44 (PE13), SV6.3, TP10.P$1
TIM1_CH4: IC3.45 (PE14), SV4.3, TP9.P$1
TIM4_CH2: IC3.60 (PD13), U2.D5
TIM4_CH3: IC3.61 (PD14), U2.D6
TIM9_CH1: IC3.4 (PE5), Q3.1 (G)
TIM10_CH1: IC3.95 (PB8), JP4.2, U2.D9
TIM11_CH1: IC3.96 (PB9), JP4.3, U2.D10
USART2_RX: IC3.87 (PD6), TP1.P$1, U2.D0
USART2_TX: IC3.86 (PD5), TP2.P$1, U2.D1
USART6_RX: IC3.64 (PC7), R46.1, X1.16 (UTXD)
USART6_TX: IC3.63 (PC6), IC4.57 (RX), SV1.2, X1.15 (URXD)
USB_D_N: J1.D-, R23.2, Z2.1
USB_D_P: J1.D+, R25.2, Z3.1
USB_ID: J1.ID (USBID), SJ3.2, Z1.1
USB_ID_: IC3.69 (PA10), SJ3.1
VBAT: C3.2, JP3.2, Q1.6 (E1), Q2.3 (D), R21.2, U3.3 (VBAT)
VBATT_IN: C33.2, IC3.6 (VBAT), R21.1, R22.1
VBUS: C1.2, C4.+, D3.A, L2.2, R2.2, R10.2, R18.1, SJ1.2, U2.5V, U2.VIN, U3.4 (VIN)
VCC: C41.2, R13.2, TP14.TP, X1.8 (VCC)
V_UNREG: C6.1, D2.A, IC2.3 (VIN), Q6.3 (D), R3.1, R7.1, SV2.2, SV3.2, SV4.2, SV5.2, SV6.2
WIFI_!HIB: IC3.7 (PC13), IC4.2 (!HIB)
WIFI_!RESET: C64.2, IC3.39 (PE8), IC4.32 (!RESET), R38.2, S6.1
WIFI_FORCE_AP: IC4.4 (FORCE_AP), R28.1
WIFI_INTR: IC3.2 (PE3), IC4.15 (HOST_INTR)
WIFI_SOP0: IC4.35 (SOP0), R35.1
WIFI_SOP1: IC4.34 (SOP1), R36.1
WIFI_SOP2: IC4.21 (SOP2/TCXO_EN), R37.1

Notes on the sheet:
Arduino Shield Headers
LCD Connector
Taken form the Repaper Dev Board
Connector and support parts
WIFI Antenna
WIFI Flash
WIFI Xtal
LQM2HPN2R2MG0L
WIFI Power
WIFI Control
values depend on crystal
default: use stm32, DNP crystal + caps
connect WP/HOLD
Place Caps for 405 0R for 4x1
STM Power
STM Main Xtal
JTAG SWD
Port A
Port B
Port C
Port D
C9 (on pin 48) DNP for 405
spec
close for OTG
/ JOY_CEN
3.6V version
depends on led
/ BOOT1
low ESR
NOTE: need to disable spi when screen power is off
MicroSD Card
WS2812
Servo / WS2812 Headers
Port E
USB OTG
Power
LEDs
ESP8266
/CC3100 UART
ADC Inputs

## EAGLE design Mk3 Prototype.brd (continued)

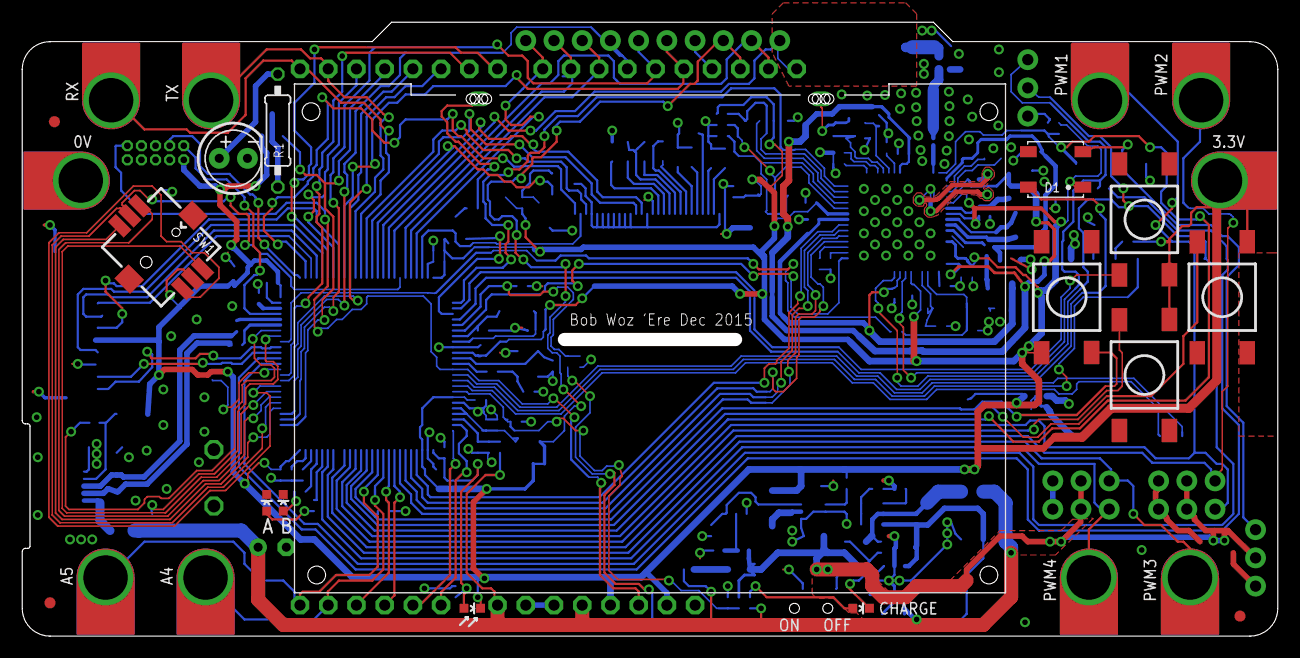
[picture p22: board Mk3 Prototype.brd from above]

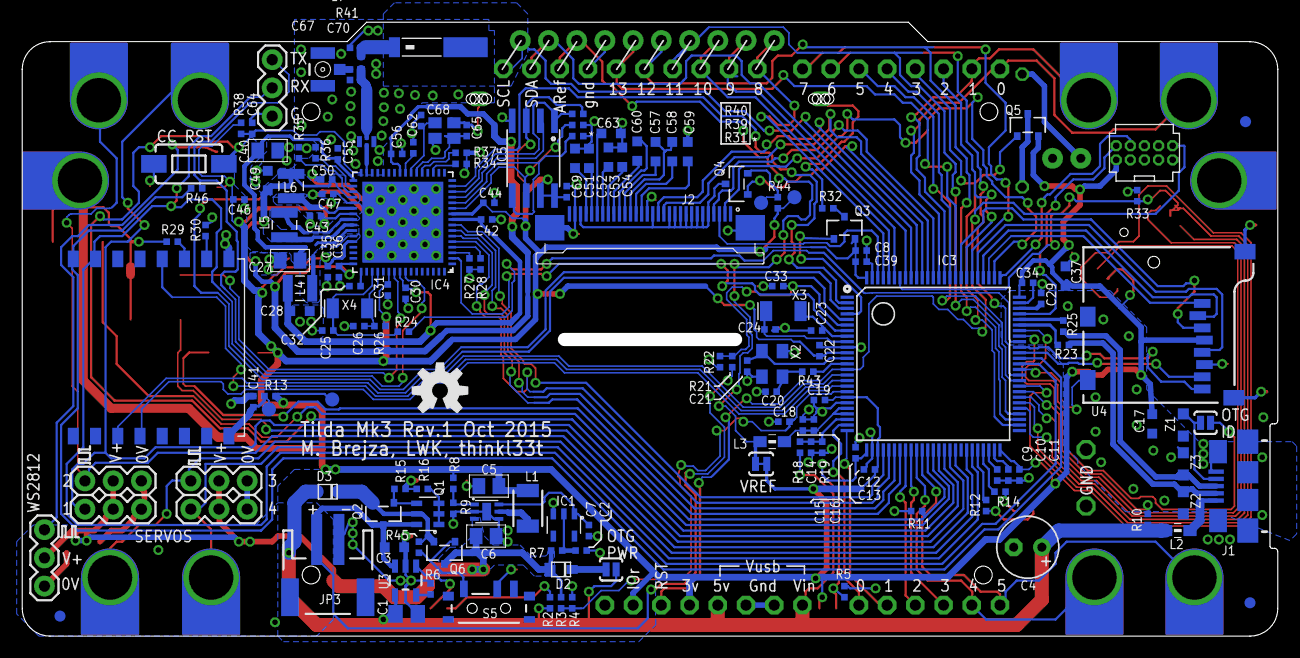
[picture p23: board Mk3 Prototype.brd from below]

Board: 2 copper layers, 113.0 x 55.2 mm, 192 parts (166 on the bottom side), 158 nets.

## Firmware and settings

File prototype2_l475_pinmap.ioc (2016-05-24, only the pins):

Mcu.UserName=STM32L475VGTx
PA0.Signal=S_TIM2_CH1_ETR
PA1.Signal=S_TIM2_CH2
PA10.Signal=USB_OTG_FS_ID
PA11.Signal=USB_OTG_FS_DM
PA12.Signal=USB_OTG_FS_DP
PA13.Signal=SYS_JTMS-SWDIO
PA14.Signal=SYS_JTCK-SWCLK
PA15.GPIO_Label=button
PA15.Signal=GPIO_Input
PA2.Signal=S_TIM2_CH3
PA3.Signal=S_TIM2_CH4
PA4.Signal=SPI1_NSS
PA5.Signal=COMP_DAC12_group
PA6.Signal=SPI1_MISO
PA7.Signal=SPI1_MOSI
PA8.GPIO_Label=SDIO_SW
PA8.Signal=GPIO_Input
PA9.Signal=USB_OTG_FS_VBUS
PB0.Signal=ADCx_IN15
PB1.GPIO_Label=ADC_LIGHT
PB1.Signal=ADCx_IN16
PB10.Signal=SPI2_SCK
PB12.Signal=SPI2_NSS
PB13.Signal=TIM15_CH1N
PB14.Signal=SPI2_MISO
PB15.Signal=SPI2_MOSI
PB3.Signal=SPI3_SCK
PB4.Signal=SPI3_MISO
PB5.Signal=SPI3_MOSI
PB6.Signal=USART1_TX
PB7.Signal=USART1_RX
PB8.Signal=I2C1_SCL
PB9.Signal=I2C1_SDA
PC0.Signal=I2C3_SCL
PC1.Signal=I2C3_SDA
PC10.Signal=SDMMC1_D2
PC11.Signal=SDMMC1_D3
PC12.Signal=SDMMC1_CK
PC13.GPIO_Label=IMU_IRQ2
PC13.Signal=GPIO_Input
PC14/OSC32_IN.Signal=RCC_OSC32_IN
PC15/OSC32_OUT.Signal=RCC_OSC32_OUT
PC3.GPIO_Label=ADC_VIN
PC3.Signal=ADCx_IN4
PC4.Signal=USART3_TX
PC5.Signal=USART3_RX
PC6.GPIO_Label=cc_hib
PC6.Signal=GPIO_Output
PC7.GPIO_Label=TIM8_CH2 (LED)
PC7.Signal=S_TIM8_CH2
PC8.Signal=SDMMC1_D0
PC9.Signal=SDMMC1_D1
PD0.Signal=FMC_D2
PD1.Signal=FMC_D3
PD10.Signal=GPIO_Input
PD11.Signal=GPIO_Input
PD12.GPIO_Label=buzz tim4_ch1
PD12.Signal=S_TIM4_CH1
PD13.Signal=GPIO_Output
PD14.Signal=FMC_D0
PD15.Signal=FMC_D1
PD2.Signal=SDMMC1_CMD
PD3.Signal=GPIO_Input
PD4.Signal=FMC_NOE
PD5.Signal=FMC_NWE
PD6.Signal=GPIO_Input
PD7.Signal=FMC_NE1
PD8.Signal=GPIO_Input
PD9.Signal=GPIO_Input
PE0.Signal=GPIO_Input
PE1.GPIO_Label=BL TIM17_CH1
PE1.Signal=S_TIM17_CH1
PE10.Signal=FMC_D7
PE11.Signal=S_TIM1_CH2
PE12.GPIO_Label=LED
PE12.Signal=GPIO_Output
PE13.Signal=SPI1_SCK
PE14.Signal=S_TIM1_CH4
PE15.GPIO_Label=LED
PE15.Signal=GPIO_Output
PE2.Signal=FMC_A23
PE3.GPIO_Label=CC_RST
PE3.Signal=GPIO_Output
PE4.GPIO_Label=CC_IRQ
PE4.Signal=GPIO_Output
PE5.GPIO_Label=TEAR
PE5.Signal=GPIO_Input
PE6.GPIO_Label=LCD_MODE
PE6.Signal=GPIO_Output
PE7.Signal=FMC_D4
PE8.Signal=FMC_D5
PE9.Signal=FMC_D6

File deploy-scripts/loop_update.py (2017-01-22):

#!/usr/bin/env python
# This file is part of the OpenMV project.
# Copyright (c) 2013/2014 Ibrahim Abdelkader <i.abdalkader@gmail.com>
# This work is licensed under the MIT license, see the file LICENSE for
# details.
#
# Adapted by the EMF Badge team as a simple one-script updater

"""This module implements enough functionality to program the STM32F4xx over
DFU, without requiringdfu-util.

See app note AN3156 for a description of the DFU protocol.
See document UM0391 for a dscription of the DFuse file.
"""

from __future__ import print_function

import argparse
import re
import struct
import sys
import usb.core
import usb.util
import zlib
import urllib
import os
import time

# VID/PID
__VID = 0x0483
__PID = 0xdf11

# USB request __TIMEOUT
__TIMEOUT = 4000

# DFU commands
__DFU_DETACH    = 0
__DFU_DNLOAD    = 1
__DFU_UPLOAD    = 2
__DFU_GETSTATUS = 3
__DFU_CLRSTATUS = 4
__DFU_GETSTATE  = 5
__DFU_ABORT     = 6

# DFU status
__DFU_STATE_APP_IDLE                 = 0x00
__DFU_STATE_APP_DETACH               = 0x01
__DFU_STATE_DFU_IDLE                 = 0x02
__DFU_STATE_DFU_DOWNLOAD_SYNC        = 0x03
__DFU_STATE_DFU_DOWNLOAD_BUSY        = 0x04
__DFU_STATE_DFU_DOWNLOAD_IDLE        = 0x05
__DFU_STATE_DFU_MANIFEST_SYNC        = 0x06
__DFU_STATE_DFU_MANIFEST             = 0x07
__DFU_STATE_DFU_MANIFEST_WAIT_RESET  = 0x08
__DFU_STATE_DFU_UPLOAD_IDLE          = 0x09
__DFU_STATE_DFU_ERROR                = 0x0a

_DFU_DESCRIPTOR_TYPE                 = 0x21


# USB device handle
__dev = None

__verbose = None

# USB DFU interface
__DFU_INTERFACE = 0

import inspect
if 'length' in inspect.getargspec(usb.util.get_string).args:
    # PyUSB 1.0.0.b1 has the length argument
    def get_string(dev, index):
        return usb.util.get_string(dev, 255, index)
else:
    # PyUSB 1.0.0.b2 dropped the length argument
    def get_string(dev, index):
        return usb.util.get_string(dev, index)


def init():
    """Initializes the found DFU device so that we can program it."""
    global __dev
    devices = get_dfu_devices(idVendor=__VID, idProduct=__PID)
    if not devices:
        raise OSError('No DFU Devices')
    if len(devices) > 1:
        raise ValueError("Multiple DFU devices found")
    __dev = devices[0]

    # Claim DFU interface
    usb.util.claim_interface(__dev, __DFU_INTERFACE)

    # Clear status
    clr_status()


def clr_status():
    """Clears any error status (perhaps left over from a previous session)."""
    __dev.ctrl_transfer(0x21, __DFU_CLRSTATUS, 0, __DFU_INTERFACE,
                        None, __TIMEOUT)


def get_status():
    """Get the status of the last operation."""
    stat = __dev.ctrl_transfer(0xA1, __DFU_GETSTATUS, 0, __DFU_INTERFACE,
                               6, 20000)
    # print (__DFU_STAT[stat[4]], stat)
    return stat[4]


def mass_erase():
    """Performs a MASS erase (i.e. erases the entire device."""
    # Send DNLOAD with first byte=0x41
    __dev.ctrl_transfer(0x21, __DFU_DNLOAD, 0, __DFU_INTERFACE,
                        "\x41", __TIMEOUT)

    # Execute last command
    if get_status() != __DFU_STATE_DFU_DOWNLOAD_BUSY:
        raise Exception("DFU: erase failed")

    # Check command state
    if get_status() != __DFU_STATE_DFU_DOWNLOAD_IDLE:
        raise Exception("DFU: erase failed")


def page_erase(addr):
    """Erases a single page."""
    if __verbose:
        print("Erasing page: 0x%x..." % (addr))

    # Send DNLOAD with first byte=0x41 and page address
    buf = struct.pack("<BI", 0x41, addr)
    __dev.ctrl_transfer(0x21, __DFU_DNLOAD, 0, __DFU_INTERFACE, buf, __TIMEOUT)

    # Execute last command
    if get_status() != __DFU_STATE_DFU_DOWNLOAD_BUSY:
        raise Exception("DFU: erase failed")

    # Check command state
    if get_status() != __DFU_STATE_DFU_DOWNLOAD_IDLE:

        raise Exception("DFU: erase failed")


def set_address(addr):
    """Sets the address for the next operation."""
    # Send DNLOAD with first byte=0x21 and page address
    buf = struct.pack("<BI", 0x21, addr)
    __dev.ctrl_transfer(0x21, __DFU_DNLOAD, 0, __DFU_INTERFACE, buf, __TIMEOUT)

    # Execute last command
    if get_status() != __DFU_STATE_DFU_DOWNLOAD_BUSY:
        raise Exception("DFU: set address failed")

    # Check command state
    if get_status() != __DFU_STATE_DFU_DOWNLOAD_IDLE:
        raise Exception("DFU: set address failed")


def write_memory(addr, buf, progress=None, progress_addr=0, progress_size=0):
    """Writes a buffer into memory. This routine assumes that memory has
    already been erased.
    """

    xfer_count = 0
    xfer_bytes = 0
    xfer_total = len(buf)
    xfer_base = addr

    while xfer_bytes < xfer_total:
        if __verbose and xfer_count % 512 == 0:
            print ("Addr 0x%x %dKBs/%dKBs..." % (xfer_base + xfer_bytes,
                                                 xfer_bytes // 1024,
                                                 xfer_total // 1024))
        if progress and xfer_count % 256 == 0:
            progress(progress_addr, xfer_base + xfer_bytes - progress_addr,
                     progress_size)

        # Set mem write address
        set_address(xfer_base+xfer_bytes)

        # Send DNLOAD with fw data
        chunk = min(64, xfer_total-xfer_bytes)
        __dev.ctrl_transfer(0x21, __DFU_DNLOAD, 2, __DFU_INTERFACE,
                            buf[xfer_bytes:xfer_bytes + chunk], __TIMEOUT)

        # Execute last command
        if get_status() != __DFU_STATE_DFU_DOWNLOAD_BUSY:
            raise Exception("DFU: write memory failed")

        # Check command state
        if get_status() != __DFU_STATE_DFU_DOWNLOAD_IDLE:
            raise Exception("DFU: write memory failed")

        xfer_count += 1
        xfer_bytes += chunk


def write_page(buf, xfer_offset):
    """Writes a single page. This routine assumes that memory has already
    been erased.
    """

    xfer_base = 0x08000000

    # Set mem write address
    set_address(xfer_base+xfer_offset)

    # Send DNLOAD with fw data
    __dev.ctrl_transfer(0x21, __DFU_DNLOAD, 2, __DFU_INTERFACE, buf, __TIMEOUT)

    # Execute last command
    if get_status() != __DFU_STATE_DFU_DOWNLOAD_BUSY:
        raise Exception("DFU: write memory failed")

    # Check command state
    if get_status() != __DFU_STATE_DFU_DOWNLOAD_IDLE:
        raise Exception("DFU: write memory failed")

    if __verbose:
        print ("Write: 0x%x " % (xfer_base + xfer_offset))


def exit_dfu():
    """Exit DFU mode, and start running the program."""

    # set jump address
    set_address(0x08000000)

    # Send DNLOAD with 0 length to exit DFU
    __dev.ctrl_transfer(0x21, __DFU_DNLOAD, 0, __DFU_INTERFACE,
                        None, __TIMEOUT)

    try:
        # Execute last command
        if get_status() != __DFU_STATE_DFU_MANIFEST:
            print("Failed to reset device")

        # Release device
        usb.util.dispose_resources(__dev)
    except:
        pass


def named(values, names):
    """Creates a dict with `names` as fields, and `values` as values."""
    return dict(zip(names.split(), values))


def consume(fmt, data, names):
    """Parses the struct defined by `fmt` from `data`, stores the parsed fields
    into a named tuple using `names`. Returns the named tuple, and the data
    with the struct stripped off."""
    size = struct.calcsize(fmt)
    return named(struct.unpack(fmt, data[:size]), names), data[size:]


def cstring(string):
    """Extracts a null-terminated string from a byte array."""
    return string.decode('utf-8').split('\0', 1)[0]


def compute_crc(data):
    """Computes the CRC32 value for the data passed in."""
    return 0xFFFFFFFF & -zlib.crc32(data) - 1


def read_dfu_file(filename):
    """Reads a DFU file, and parses the individual elements from the file.
    Returns an array of elements. Each element is a dictionary with the
    following keys:
        num     - The element index
        address - The address that the element data should be written to.
        size    - The size of the element ddata.
        data    - The element data.
    If an error occurs while parsing the file, then None is returned.
    """

    print("File: {}".format(filename))
    with open(filename, 'rb') as fin:
        data = fin.read()
    crc = compute_crc(data[:-4])
    elements = []

    # Decode the DFU Prefix
    #
    # <5sBIB
    #   <   little endian
    #   5s  char[5]     signature   "DfuSe"
    #   B   uint8_t     version     1
    #   I   uint32_t    size        Size of the DFU file (not including suffix)
    #   B   uint8_t     targets     Number of targets
    dfu_prefix, data = consume('<5sBIB', data,
                               'signature version size targets')
    print ("    %(signature)s v%(version)d, image size: %(size)d, "
           "targets: %(targets)d" % dfu_prefix)
    for target_idx in range(dfu_prefix['targets']):
        # Decode the Image Prefix
        #
        # <6sBI255s2I
        #   <   little endian
        #   6s      char[6]     signature   "Target"
        #   B       uint8_t     altsetting
        #   I       uint32_t    named       bool indicating if a name was used
        #   255s    char[255]   name        name of the target
        #   I       uint32_t    size        size of image (not incl prefix)
        #   I       uint32_t    elements    Number of elements in the image
        img_prefix, data = consume('<6sBI255s2I', data,
                                   'signature altsetting named name '
                                   'size elements')
        img_prefix['num'] = target_idx
        if img_prefix['named']:
            img_prefix['name'] = cstring(img_prefix['name'])
        else:
            img_prefix['name'] = ''
        print('    %(signature)s %(num)d, alt setting: %(altsetting)s, '
              'name: "%(name)s", size: %(size)d, elements: %(elements)d'
              % img_prefix)

        target_size = img_prefix['size']
        target_data, data = data[:target_size], data[target_size:]
        for elem_idx in range(img_prefix['elements']):
            # Decode target prefix
            #   <   little endian
            #   I   uint32_t    element address
            #   I   uint32_t    element size
            elem_prefix, target_data = consume('<2I', target_data, 'addr size')
            elem_prefix['num'] = elem_idx
            print('      %(num)d, address: 0x%(addr)08x, size: %(size)d'
                  % elem_prefix)
            elem_size = elem_prefix['size']
            elem_data = target_data[:elem_size]
            target_data = target_data[elem_size:]
            elem_prefix['data'] = elem_data
            elements.append(elem_prefix)

        if len(target_data):
            print("target %d PARSE ERROR" % target_idx)

    # Decode DFU Suffix
    #   <   little endian
    #   H   uint16_t    device  Firmware version
    #   H   uint16_t    product
    #   H   uint16_t    vendor
    #   H   uint16_t    dfu     0x11a   (DFU file format version)
    #   3s  char[3]     ufd     'UFD'
    #   B   uint8_t     len     16
    #   I   uint32_t    crc32
    dfu_suffix = named(struct.unpack('<4H3sBI', data[:16]),
                       'device product vendor dfu ufd len crc')
    print ('    usb: %(vendor)04x:%(product)04x, device: 0x%(device)04x, '
           'dfu: 0x%(dfu)04x, %(ufd)s, %(len)d, 0x%(crc)08x' % dfu_suffix)
    if crc != dfu_suffix['crc']:
        print("CRC ERROR: computed crc32 is 0x%08x" % crc)
        return
    data = data[16:]
    if data:
        print("PARSE ERROR")
        return

    return elements


class FilterDFU(object):
    """Class for filtering USB devices to identify devices which are in DFU
    mode.
    """

    def __call__(self, device):
        for cfg in device:
            for intf in cfg:
                return (intf.bInterfaceClass == 0xFE and
                        intf.bInterfaceSubClass == 1)


def get_dfu_devices(*args, **kwargs):
    """Returns a list of USB device which are currently in DFU mode.
    Additional filters (like idProduct and idVendor) can be passed in to
    refine the search.
    """
    # convert to list for compatibility with newer pyusb
    return list(usb.core.find(*args, find_all=True,
                              custom_match=FilterDFU(), **kwargs))


def get_memory_layout(device):
    """Returns an array which identifies the memory layout. Each entry
    of the array will contain a dictionary with the following keys:
        addr        - Address of this memory segment
        last_addr   - Last address contained within the memory segment.
        size        - size of the segment, in bytes
        num_pages   - number of pages in the segment
        page_size   - size of each page, in bytes
    """
    cfg = device[0]
    intf = cfg[(0, 0)]
    mem_layout_str = get_string(device, intf.iInterface)
    mem_layout = mem_layout_str.split('/')
    addr = int(mem_layout[1], 0)
    segments = mem_layout[2].split(',')
    seg_re = re.compile(r'(\d+)\*(\d+)(.)(.)')
    result = []
    for segment in segments:
        seg_match = seg_re.match(segment)
        num_pages = int(seg_match.groups()[0], 10)
        page_size = int(seg_match.groups()[1], 10)
        multiplier = seg_match.groups()[2]
        if multiplier == 'K':
            page_size *= 1024
        if multiplier == 'M':
            page_size *= 1024 * 1024
        size = num_pages * page_size
        last_addr = addr + size - 1
        result.append(named((addr, last_addr, size, num_pages, page_size),
                      "addr last_addr size num_pages page_size"))
        addr += size
    return result


def list_dfu_devices(*args, **kwargs):
    """Prints a lits of devices detected in DFU mode."""
    devices = get_dfu_devices(*args, **kwargs)
    if not devices:
        return
    for device in devices:
        print("Bus {} Device {:03d}: ID {:04x}:{:04x}"
              .format(device.bus, device.address,
                      device.idVendor, device.idProduct))
        layout = get_memory_layout(device)
        print("Memory Layout")
        for entry in layout:
            print("    0x{:x} {:2d} pages of {:3d}K bytes"
                  .format(entry['addr'], entry['num_pages'],
                          entry['page_size'] // 1024))


def write_elements(elements, mass_erase_used, progress=None):
    """Writes the indicated elements into the target memory,
    erasing as needed.
    """

    mem_layout = get_memory_layout(__dev)
    for elem in elements:
        addr = elem['addr']
        size = elem['size']
        data = elem['data']
        elem_size = size
        elem_addr = addr
        if progress:
            progress(elem_addr, 0, elem_size)
        while size > 0:
            write_size = size
            if not mass_erase_used:
                for segment in mem_layout:
                    if addr >= segment['addr'] and \
                       addr <= segment['last_addr']:
                        # We found the page containing the address we want to
                        # write, erase it
                        page_size = segment['page_size']
                        page_addr = addr & ~(page_size - 1)
                        if addr + write_size > page_addr + page_size:
                            write_size = page_addr + page_size - addr
                        page_erase(page_addr)
                        break
            write_memory(addr, data[:write_size], progress,
                         elem_addr, elem_size)
            data = data[write_size:]
            addr += write_size
            size -= write_size
            if progress:
                progress(elem_addr, addr - elem_addr, elem_size)


def cli_progress(addr, offset, size):
    """Prints a progress report suitable for use on the command line."""
    width = 25
    done = offset * width // size
    print("\r0x{:08x} {:7d} [{}{}] {:3d}% "
          .format(addr, size, '=' * done, ' ' * (width - done),
                  offset * 100 // size), end="")
    sys.stdout.flush()
    if offset == size:
        print("")


def main():


    """Test program for verifying this files functionality."""
    global __verbose
    # Parse CMD args
    parser = argparse.ArgumentParser(description='DFU Python Util')
    #parser.add_argument("path", help="file path")
    parser.add_argument(
        "-l", "--list",
        help="list available DFU devices",
        action="store_true",
        default=False
    )
    parser.add_argument(
        "-u", "--upload",
        help="read file from DFU device",
        dest="path",
        default=False
    )
    parser.add_argument(
        "-v", "--verbose",
        help="increase output verbosity",
        action="store_true",
        default=False
    )
    args = parser.parse_args()

    __verbose = args.verbose

    try:
        if args.list:
            list_dfu_devices(idVendor=__VID, idProduct=__PID)
            return

        init()
        print("We found your badge. So far, so good...")

        mass_erase()

        elements = read_dfu_file("firmware.dfu")
        if not elements:
            return
        write_elements(elements, True, progress=cli_progress)

        raw_input("All done. Press enter to continue.")
    except ValueError as e:
        print("Error: %s" %(e))
    except OSError:
        pass
    return

if __name__ == '__main__':
    while True:
        main()

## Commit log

2015-08-29 Throwing initial parts on board for prototype
    [Mk3 Prototype.brd, Mk3 Prototype.sch]
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2015-08-29 CC3100 Basic power hook up done
    [Mk3 Prototype.brd, Mk3 Prototype.sch]
2015-08-29 done stm32 power, HSE, SWD, SD card, some usb
    [Mk3 Prototype.brd, Mk3 Prototype.sch]
2015-08-29 finished stm32 power, done sd power
    [Mk3 Prototype.brd, Mk3 Prototype.sch]
2015-08-29 adding large edge connectors
    [Mk3 Prototype.brd, Mk3 Prototype.sch]
2015-08-30 initial place and route of wifi section
    [Mk3 Prototype.brd, Mk3 Prototype.sch]
2015-08-30 started to wire the stm32, very rough route to get idea of spacing stuff out
    [Mk3 Prototype.brd, Mk3 Prototype.sch]
2015-08-30 moving a few parts around
    [Mk3 Prototype.brd, Mk3 Prototype.sch]
2015-08-30 added some comments, moved a couple of things around
    [Mk3 Prototype.brd, Mk3 Prototype.sch]
2015-08-31 Lots of schematic clean up
    [Mk3 Prototype.brd, Mk3 Prototype.sch]
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2015-08-31 starting stm32 100pin schematic
    [Mk3 Prototype.brd, Mk3 Prototype.sch]
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2015-08-31 added servos and neopixel
    [Mk3 Prototype.brd, Mk3 Prototype.sch]
2015-08-31 wired servos and a few control signals
    [Mk3 Prototype.brd, Mk3 Prototype.sch]
2015-09-01 adding esp, bit more wiring
    [Mk3 Prototype.brd, Mk3 Prototype.sch]
2015-09-01 wired a few more things
    [Mk3 Prototype.brd, Mk3 Prototype.sch]
2015-09-01 a few notes added
    [Mk3 Prototype.brd, Mk3 Prototype.sch]
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2015-09-06 all peripherals assigned to stm32
    [Mk3 Prototype.brd, Mk3 Prototype.sch]
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2015-09-06 few notes added, some minor routing
    [Mk3 Prototype.brd, Mk3 Prototype.sch]
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2015-09-07 power section worked on
    [Mk3 Prototype.brd, Mk3 Prototype.sch]
2015-09-07 made gpio headers stripbord happy
    [Mk3 Prototype.brd, Mk3 Prototype.sch]
2015-09-08 musical spi ports complete
    [Mk3 Prototype.brd, Mk3 Prototype.sch]
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2015-09-08 a little more decoupling
    [Mk3 Prototype.brd, Mk3 Prototype.sch]
2015-09-08 improved placement of flash IC
    [Mk3 Prototype.brd, Mk3 Prototype.sch]
2015-09-08 some more power routing for the cc
    [Mk3 Prototype.brd, Mk3 Prototype.sch]
2015-09-09 added low voltage cutoff
    [Mk3 Prototype.brd, Mk3 Prototype.sch]
2015-09-09 moving pins so the lcd has its hardware CS
    [Mk3 Prototype.brd, Mk3 Prototype.sch]
2015-09-09 added notes, increased via size
    [Mk3 Prototype.brd, Mk3 Prototype.sch]
2015-09-10 added two status leds
    [Mk3 Prototype.brd, Mk3 Prototype.sch]
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2015-09-12 bit of tidying up
    [Mk3 Prototype.brd, Mk3 Prototype.sch]
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2015-09-12 redone some of the cc spi routing
    [Mk3 Prototype.brd]
2015-09-12 moved routing a little
    [Mk3 Prototype.brd]
2015-09-13 improving routing around usb
    [Mk3 Prototype.brd, Mk3 Prototype.sch]
2015-09-13 added part no for mosfets
    [Mk3 Prototype.brd, Mk3 Prototype.sch]
2015-09-13 bit of wiring and routing
    [Mk3 Prototype.brd, Mk3 Prototype.sch]
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2015-09-27 chnaged regulator to ncp..., all routed (for now)
    [Mk3 Prototype.brd, Mk3 Prototype.sch]
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2015-10-29 lots of cleaing up, silk screen, drc fixes
    [Mk3 Prototype.brd, Mk3 Prototype.sch]
2015-10-29 more little bits and pieces; current shunt on esp
    [Mk3 Prototype.brd, Mk3 Prototype.sch]
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2015-10-29 minor routing updates, cam now has tNames, bNames
    [Mk3 Prototype.brd]
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2015-12-15 Removed errant R42 resisitor and old antenna footprint
    [Mk3 Prototype.brd, Mk3 Prototype.sch]
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2016-02-01 added note on R45, added value to stm32 crystal
    [Mk3 Prototype.brd, Mk3 Prototype.sch]
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2016-02-01 updating some part values from the spreadsheet bom
    [Mk3 Prototype.brd, Mk3 Prototype.sch]
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2016-04-08 started to rework pin mapping a little so the lcd uses the FSMC pins
    [Mk3 Prototype2.brd, Mk3 Prototype2.sch, cc3100-breakout.brd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]
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2016-04-22 fixing outline
    [Mk3 Prototype2.brd]
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2016-04-28 Move outline to a part, including edge pads clean up outline around USB socket to make it easier to mill clean up major GND pours in board
    [Mk3 Prototype2.brd, Mk3 Prototype2.sch]
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2016-04-29 Lots of clean up around via placement and trace angle swapped out micro python logo for silk only version
    [Mk3 Prototype2.brd, Mk3 Prototype2.sch]
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2016-04-29 Add Micro Python logo to front of PCB in white and gold version to compare with white only version on the back
    [Mk3 Prototype2.brd, Mk3 Prototype2.sch]
2016-04-29 Move lanyard holes to board out line part
    [Mk3 Prototype2.brd, Mk3 Prototype2.sch]
2016-04-29 moved switches down, changed imu wiring a little
    [Mk3 Prototype2.brd, Mk3 Prototype2.sch]
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2016-04-29 Fix up via clearance
    [Mk3 Prototype2.brd]
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2016-05-08 bom mostly complete (just order numbers for generic passives missing)
    [Mk3 Prototype2.brd, Mk3 Prototype2.sch]
2016-05-13 Add full part for LCD out line. update LCD connector to connector part update some resistor parts name
    [Mk3 Prototype2.brd, Mk3 Prototype2.sch]
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2016-05-17 starting v0.3 boards, corrected LGA12,LGA14 pin assignments after mirroring
    [Mk3 Prototype3.brd, Mk3 Prototype3.sch]
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2016-05-24 cc spi clk moved to allow dac, led fet moved, ws2812 on timer
    [Mk3 Prototype3.brd, Mk3 Prototype3.sch]
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2016-05-26 Angle and clearance tidy
    [Mk3 Prototype3.brd, Mk3 Prototype3.sch]
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2016-05-26 fixing for eagle 6
    [Mk3 Prototype3.brd]
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2016-05-27 Rework entier power section layout on schematic
    [Mk3 Prototype3.brd, Mk3 Prototype3.sch]
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2016-06-03 Revert Prototype3 files to as sent for PCB fab
    [Mk3 Prototype3.brd, Mk3 Prototype3.sch]
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2016-06-03 Flip front text around
    [Mk3 v3.1415926535.brd]
2016-06-04 Sponsor logos to rear Note this moves the files to Eagle 7
    [Mk3 v3.1415926535.brd, Mk3 v3.1415926535.sch]
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2016-06-05 Last footprint change and lots a trace clean up done
    [Mk3 v3.1415926535.brd, Mk3 v3.1415926535.sch]
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2016-06-06 Do Not use [t|b]Names layer for silkscreen It fuck things up when you panelize
    [Mk3 v3.1415926535.brd, Mk3 v3.1415926535.sch]
2016-06-06 Final BRD commit do not change it again
    [Mk3 v3.1415926535.brd]
2016-06-06 Update all values for L4 variant by default
    [Mk3 v3.1415926535.brd, Mk3 v3.1415926535.sch]
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2016-07-11 fixing error: line 7053, column 132: redefinition of name 'LOGO1' in tag <element>
    [Mk3 Prototype3.brd]
2016-07-20 Correct joystick trace names
    [Mk3 v3.1415926535.brd, Mk3 v3.1415926535.sch]
2016-07-20 Correct joystick part in the LBR
    [Mk3 v3.1415926535.brd, Mk3 v3.1415926535.sch]
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

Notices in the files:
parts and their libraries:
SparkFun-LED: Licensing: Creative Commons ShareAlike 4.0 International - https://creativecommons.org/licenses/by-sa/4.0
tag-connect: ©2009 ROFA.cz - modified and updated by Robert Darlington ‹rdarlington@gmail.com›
